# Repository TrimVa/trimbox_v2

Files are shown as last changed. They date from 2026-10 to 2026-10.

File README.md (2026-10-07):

# TrimBox

Enregistreur de télémétrie **GPS + inertiel** pour voitures radiocommandées,
avec **chronométrage au tour** affiché et annoncé sur la radio, **console web**
d'analyse et **mise à jour par Wi-Fi**. Construit autour d'un **ESP32-S3**.

> **État :** firmware **2.0-a16**, console **1.7.18**. Tout est écrit et testé
> sur PC, dans un navigateur et dans un émulateur ESP32-S3. **Essais sur le
> vrai matériel en cours** : GPS, IMU et script Lua sur la MT12 validés ; reste
> le roulage. Voir [les bancs d'essai](#bancs-dessai-à-la-réception-du-matériel).

---

## Sommaire

1. [Ce que fait le module](#ce-que-fait-le-module)
2. [Matériel](#matériel)
3. [Câblage](#câblage)
4. [Mise en route](#mise-en-route)
5. [Utilisation au bord de la piste](#utilisation-au-bord-de-la-piste)
6. [Console web](#console-web)
7. [Radio MT12 et script Lua](#radio-mt12-et-script-lua)
8. [Mises à jour du firmware](#mises-à-jour-du-firmware)
9. [Personnalisation](#personnalisation)
10. [Moniteur série et DEL](#moniteur-série-et-del)
11. [Sécurité et robustesse](#sécurité-et-robustesse)
12. [Dépannage](#dépannage)
13. [Contenu du dépôt](#contenu-du-dépôt)
14. [Compilation et tests automatiques](#compilation-et-tests-automatiques)
15. [Limites connues et suite du projet](#limites-connues-et-suite-du-projet)
16. [Documentation](#documentation)

---

## Ce que fait le module

| Fonction | Détail |
|---|---|
| **Enregistrement autonome** | GPS à 25 Hz + accéléromètre et gyroscope, sur la mémoire interne de 16 Mo. Aucun téléphone nécessaire pendant le roulage. |
| **Autonomie mémoire** | **01h42min à 25 Hz**, 02h08min à 20 Hz, 04h17min à 10 Hz, 08h34min à 5 Hz, 42h52min à 1 Hz (154 333 points). |
| **Enregistrement automatique** | l'enregistrement s'ouvre tout seul dès que la voiture roule et se ferme après 30 s à l'arrêt : **un roulage = une session**, sans rien toucher. Réglable, ou remplaçable par les boutons de la console. |
| **Filtres d'enregistrement** | attente du GPS, pause sans signal, extinction après inactivité. Rien n'est stocké au stand. |
| **Chrono embarqué** | calculé dans le module à 25 Hz, temps interpolés entre deux mesures (précision de l'ordre de la milliseconde). Mode **circuit** (une ligne, un temps par tour) ou **dragster** (départ + arrivée, chronos 0-30 / 0-50 / 0-80 km/h et 25 / 50 / 100 m). |
| **Pose de ligne depuis la radio** | voiture **arrêtée sur la ligne** : la commande arme la ligne, qui est posée dans le sens du départ dès que la voiture démarre (dans les 10 s) ; ce départ compte. Voiture **lancée** : la ligne est posée là où passe la voiture, perpendiculaire à sa trajectoire. Conservée d'une session à l'autre. |
| **Télémétrie radio** | position GPS, vitesse, état, et un message par tour (temps + écart au meilleur) vers la MT12, qui **annonce les temps à voix haute**. |
| **Console Bluetooth** | depuis la page GitHub du projet, sur Chrome Android. Comme le Wi-Fi, le Bluetooth se coupe quand la voiture roule et revient 30 s après l'arrêt. |
| **Console Wi-Fi** | le module ouvre son propre réseau quand la voiture est arrêtée depuis 30 s, et le coupe dès qu'elle roule. Fonctionne aussi sur **iPhone**, sans Internet. |
| **Analyse** | tracé coloré par vitesse, zoom, tours et parcours, forces G, temps en l'air, statistiques au survol du tracé, comparaison de sessions (portion choisie en glissant sur le profil, statistiques par session). Les **lignes posées depuis la radio** sont reprises d'office, et les **tours calculés en course** par le module s'affichent à côté de ceux de la console. |
| **Exports** | VBO (RaceChrono, Circuit Tools), CSV, GPX ; import de ces mêmes formats. |
| **Mise à jour Wi-Fi** | depuis le téléphone, avec retour automatique à la version précédente si la nouvelle ne démarre pas correctement. |

---

## Matériel

| Élément | Référence utilisée | Rôle |
|---|---|---|
| Carte | **ESP32-S3-DevKitC-1, module WROOM-1-N16R8** | 16 Mo de flash, 8 Mo de PSRAM, Bluetooth, Wi-Fi |
| GPS | **HGLRC M100 Mini** (u-blox M10) | position et vitesse à 25 Hz |
| Centrale inertielle | module **LSM6DS3 / LSM6DS3TR-C** (I2C) | accélérations ±16 g, rotations ±2000 °/s |
| Récepteur | **RadioMaster ER5C-i** (ExpressLRS 2,4 GHz) | commande de la voiture + liaison CRSF avec le module |
| Radio | **RadioMaster MT12** (EdgeTX) | affichage du chrono, pose des lignes |
| ESC | **XC-E8** | aucune liaison : son port X-Bus est une entrée (voir ci-dessous) |
| Alimentation | régulateur abaisseur **5 V, ≥ 1 A** | depuis le BEC de l'ESC (6 à 8,4 V) |

Au banc, l'USB de la carte suffit à tout alimenter.

⚠️ **Le module ne pilote jamais la voiture.** Direction et ESC restent sur
les sorties du récepteur : si le module plante, la voiture reste pilotable.

---

## Câblage

Schéma de câblage

Schéma vectoriel : [SVG](docs/cablage-trimbox-s3.svg) · [PDF à imprimer](docs/cablage-trimbox-s3.pdf) (régénéré par `tools/gen_cablage.py`).

| Module | Broche du module | ESP32-S3-DevKitC-1 |
|---|---|---|
| **GPS M100 Mini** | VCC | **5V** |
| | GND | GND |
| | TX | **GPIO 18** |
| | RX | **GPIO 17** |
| **IMU LSM6DS3** | VCC | **3V3** |
| | GND | GND |
| | SDA | **GPIO 8** |
| | SCL | **GPIO 9** |
| **Récepteur ER5C-i** | sortie 2 (Serial TX) | **GPIO 16** |
| | sortie 3 (Serial RX) | **GPIO 15** |
| | − | GND |
| **Alimentation (voiture)** | régulateur 5 V | **5V** + GND |

**Boîtier imprimé 3D (1/10)** : [docs/boitier/trimbox-boitier.3mf](docs/boitier/trimbox-boitier.3mf),
sans aucune vis : carte clipsée dans le fond, GPS (antenne à l'air libre par
une ouverture) et IMU clipsés dans le couvercle, trou pour voir la DEL, dessous
plat pour adhésif double face + passants pour colliers. Mesures, impression et montage : [docs/boitier/LISEZMOI.md](docs/boitier/LISEZMOI.md).

Réglages du récepteur (interface web de l'ER5C-i, onglet *Model*) :
sorties 2 et 3 en **Serial TX / RX, protocole CRSF** ; direction sur la
sortie 1 (CH1) ; ESC sur la sortie 4 (**CH2**).

Règles à respecter :

- **Jamais plus de 3,3 V sur une broche GPIO** : l'ESP32-S3 ne tolère pas le 5 V.
- **Jamais le BEC (6 à 8,4 V) directement sur la broche 5V** de la carte :
  toujours passer par le régulateur 5 V.
- Broches à ne pas utiliser : 35, 36, 37 (mémoire PSRAM), 19 et 20 (USB),
  0, 3, 45, 46 (démarrage).
- L'IMU se visse **rigidement** sur le châssis, près du centre de gravité,
  axes alignés sur la voiture (pas sur mousse).

---

## Mise en route

Détail pas à pas : **[DEMARRAGE.md](DEMARRAGE.md)**. En résumé :

1. **Envoyer ce dépôt sur GitHub.** L'onglet **Actions** compile et teste
   tout seul (10 à 15 min la première fois).
2. **Activer GitHub Pages** (*Settings → Pages → branche `main`, dossier
   `/ (root)`*) pour la console Bluetooth en ligne.
3. **Premier flash, une seule fois, par câble depuis un ordinateur** :
   page **Releases** du dépôt → dernière version → `trimbox_s3-complet.bin`, avec
   https://espressif.github.io/esptool-js/ (Chrome ou Edge), adresse **0x0**,
   prise **USB** de la carte.
4. **Vérifier** : 30 s après la mise sous tension, le Wi-Fi
   `TrimBox-Buggy-1` apparaît (mot de passe `trimbox-rc`, à changer dans
   *Réglages → Véhicule et point d'accès*) ; http://192.168.4.1/
   affiche la console et la version du firmware en haut à droite.
5. **Radio** : copier `lua/trmbox.lua` sur la MT12 et régler le mixage de CH8
   ([lua/LISEZMOI.md](lua/LISEZMOI.md)).

---

## Utilisation au bord de la piste

1. **Brancher la batterie de la voiture.** Le module démarre toujours
   **enregistrement arrêté**.
2. **Rien à faire** : l'enregistrement démarre tout seul dès que la voiture
   roule (au-dessus du seuil d'arrêt, 5 km/h par défaut) et se ferme après
   30 s à l'arrêt. Chaque roulage donne une session. Les boutons *Démarrer*
   et *Arrêter* de la console restent disponibles, et la case **Démarrer et
   arrêter tout seul** permet de revenir à la commande manuelle.
3. **Rouler.** Le Wi-Fi **et le Bluetooth** du module se coupent dès que la
   voiture dépasse 7 km/h, pour ne pas gêner la radio ; ils reviennent seuls
   30 s après l'arrêt.
4. **Poser la ligne** (une fois par piste) : voiture **arrêtée sur la ligne**,
   sur la MT12 page *Lignes*, molette sur « Poser DEPART », **ENT**, puis
   **démarrer dans les 10 s** : la ligne est posée dans le sens du départ, et
   ce départ compte déjà. En roulant (> 7 km/h), la même commande pose la
   ligne tout de suite, là où passe la voiture.
5. **Chaque tour** : la radio annonce le temps ; double bip aigu avant
   l'annonce s'il s'agit du meilleur tour.
6. **Au stand** : 30 s après l'arrêt de la voiture, le Wi-Fi revient. Le
   téléphone s'y reconnecte, la console aussi : **télécharger** la session,
   analyser, exporter.

Mode **dragster** : poser aussi la ligne d'**arrivée** (« Poser ARRIVEE »).
Un temps par passage départ → arrivée, plus les chronos intermédiaires.

---

## Console web

Un seul fichier (`index.html`), sans aucune dépendance : elle fonctionne sans
réseau. Trois sources de données, au choix en haut de page :

| Source | Quand | Adresse |
|---|---|---|
| **Bluetooth** | Chrome sur Android, ordinateur | `https://<pseudo>.github.io/<dépôt>/` |
| **Wi-Fi** | tout téléphone, dont iPhone ; au stand | `http://192.168.4.1/` (Wi-Fi du module) |
| **Démo** | sans matériel, pour découvrir | `…/index.html?demo=1` |

Fonctions : données en direct, état de la mémoire, démarrage / arrêt et
réglages de l'enregistrement, téléchargement et effacement, analyse
(tracé, tours, dragster, G, sauts), comparaison, exports VBO / CSV / GPX,
mise à jour du firmware (en Wi-Fi), thème clair / sombre et **couleur
d'accent** au choix (bouton palette), installable comme une application
(PWA). L'en-tête affiche la version de la console et celle du firmware de la
carte connectée.

La mise en page s'adapte à l'écran : une colonne sur téléphone (dès 320 px),
une colonne plus large sur tablette. Sur ordinateur, la console occupe **toute
la largeur** avec des **onglets** *Appareil*, *Analyse*, *Sessions* et
*Réglages* ; dans chaque onglet, les panneaux se partagent la ligne.

**Fond satellite en Wi-Fi.** Le point d'accès de la TrimBox n'a pas
Internet : les images satellite passent par la **4G du téléphone**. Pour cela :

- sur Android, activez les **données mobiles quand le Wi-Fi n'a pas
  Internet** (option « Basculer vers les données mobiles » ou « Wi-Fi
  adaptatif », selon la marque) ;
- ouvrez la console dans **Chrome** (`http://192.168.4.1`), et non dans la
  fenêtre « Se connecter à TrimBox-… » qui s'ouvre toute seule : cette
  fenêtre est limitée au Wi-Fi, les images ne peuvent pas y arriver.

Sans réponse d'Internet, la console garde le fond satellite actif, affiche une
explication et réessaie toutes les 10 s : la carte apparaît dès que la 4G
répond. Le reste fonctionne à l'identique, et le téléchargement est bien plus
rapide qu'en Bluetooth. Sans réseau mobile, deux solutions :

- **après la séance** : télécharger la session (CSV / GPX / VBO), puis la
  rouvrir dans la console en ligne, avec *Ouvrir des enregistrements* ;
- **au bord de la piste** : utiliser la console en ligne connectée **par
  Bluetooth**.

**Voiture à l'arrêt.** Une voiture posée semble « dériver » de 1 à 3 m à cause
du bruit du GPS. Pour l'éviter, le firmware fige la position et met la
vitesse à 0 dès que la voiture est immobile :
- **quand** : vitesse sous 1,1 km/h pendant 0,2 s, sans mouvement vu par l'IMU ;
- **reprise** : dès que la vitesse dépasse 2,2 km/h, que l'IMU bouge, ou que la
  voiture s'est éloignée de 4 m ;
- **pour enregistrer le GPS brut** : `STILL_HOLD 0` dans `config.h`.

---

## Radio MT12 et script Lua

Script `lua/trmbox.lua` → carte SD de la radio, `SCRIPTS/TELEMETRY/`.
Mode d'emploi complet : **[lua/LISEZMOI.md](lua/LISEZMOI.md)**.

- **Page Chrono** : dernier tour en grand, numéro, écart, meilleur tour,
  tours précédents ; état du module, lignes posées, indicateur Wi-Fi.
- **Page Machine** : vitesse (0 sous 3 km/h), vitesse maximale, satellites,
  qualité de liaison, RSSI, altitude, **tension de la batterie** (capteur du
  récepteur) et **date et heure du GPS** en heure locale.
- **Page Lignes** : poser le départ, l'arrivée, effacer.
- **Mixage CH8, indispensable** : *Modèle → Mixeur → CH8*, source **MAX**,
  poids **GV9**, mode « ajouter ». Sans lui, aucune commande de pose ne part
  de la radio. La page *Lignes* affiche la valeur réelle de la voie (`CH8
  +0%`), qui doit passer à ±100 % pendant un envoi. Un inter 3 positions sur
  CH8 marche aussi sans le script (haut 0,5 s = départ, bas 0,5 à 3 s =
  arrivée, bas 3 s = effacement).
- **Réglage ExpressLRS** : *Telem Ratio* **1:16** ou plus fréquent, sinon
  des messages de tour peuvent manquer.
- **Annonces vocales** : « meilleur tour », le temps du tour, l'écart avec le
  tour précédent (« moins 0,35 », « plus 1,00 », « égal »), et les accusés
  de pose de ligne (« départ posé », « vitesse trop faible »…). Les nombres
  viennent du pack vocal de la radio ; les 12 mots du script sont fournis dans
  `lua/SOUNDS/trimbox/` (copier `lua/SOUNDS` à la racine de la carte SD). Ils
  ont été produits par `tools/sons/generer-voix.bat` avec la voix Azure du pack
  EdgeTX (liste : `tools/sons/liste-sons-mt12.csv`). Sans eux, des bips les
  remplacent. `tools/sons/generer-mot.bat` produit à la demande d'autres mots
  ou phrases avec la même voix (texte et nom demandés, écoute avant d'enregistrer).
- **Date et heure GPS** : le module envoie la trame CRSF `0x03` une fois par
  seconde. Il faut **ExpressLRS 4.1 ou plus récent** sur l'émetteur **et** sur
  le récepteur pour qu'elle soit relayée, et une version d'EdgeTX qui la
  décode : après *Découvrir les capteurs*, un capteur **`Date`** apparaît.
  Avec l'option *Ajuster l'horloge* de ce capteur, la radio se met à l'heure
  toute seule. Le script affiche l'heure locale (France par défaut, heure
  d'été automatique ; réglages `TZ_OFFSET` et `TZ_EU_DST`).

Messages envoyés à la radio (capteur `FM`) :

| Message | Sens |
|---|---|
| `L12 21.345+0.35` | tour 12 en 21,345 s, 0,35 s de plus que le meilleur |
| `S REC C` | état (REC / PAUSE / STOP / NOFIX) et lignes (C circuit, D dragster, - aucune) |
| `R 0-50 2.184` | chrono intermédiaire (dragster) |
| `K DEPART OK` | accusé de pose de ligne (ou `VIT FAIBLE`, `PAS DE FIX`, `EFFACE`) |
| `W WIFI ON` | Wi-Fi de la console allumé / coupé |
| `U MAJ OK` | étapes d'une mise à jour du firmware |

---

## Mises à jour du firmware

**Par Wi-Fi, sans ordinateur :**

1. Modifier le code dans GitHub (bouton crayon) et valider : la compilation
   repart seule.
2. Page **Releases** du dépôt → dernière version → `trimbox_s3-app.bin`
   (publiée automatiquement quand tout est vert et que `FIRMWARE_VER` a
   changé ; sinon *Actions* → compilation verte → artefact
   **firmware-s3-app**).
3. Voiture **et** enregistrement arrêtés : console Wi-Fi → **Mise à jour du
   firmware** → choisir le fichier → **Envoyer au module** (environ 10 s).
4. La console se reconnecte et affiche « ✓ Nouvelle version active ».

Filets de sécurité :

- mauvais fichier refusé avec un message clair (fichier « complet », .uf2
  de la v1, autre projet, image corrompue) ;
- l'ancienne version n'est jamais effacée pendant l'envoi ;
- la nouvelle version ne se **valide qu'après 15 s** de bon fonctionnement ;
  si elle plante ou se fige avant, le module **revient seul** à la
  précédente ;
- page de secours : http://192.168.4.1/update.

⚠️ `trimbox_s3/partitions.csv` ne doit **jamais** changer dans une mise à jour
Wi-Fi : la table de partitions ne se remplace que par câble.

---

## Personnalisation

Dans **`trimbox_s3/src/config.h`** :

| Réglage | Par défaut | Rôle |
|---|---|---|
| `DEVICE_NICKNAME` | `"Buggy 1"` | nom du véhicule **par défaut** (16 caractères max) : `TrimBox Buggy 1` en Bluetooth, `TrimBox-Buggy-1` en Wi-Fi ; se change ensuite dans la console |
| `WIFI_PASS` | `"trimbox-rc"` | mot de passe Wi-Fi **par défaut** (8 à 63 caractères) ; se change dans la console |
| `WIFI_AUTO_DEFAULT` | `1` | Wi-Fi automatique à l'arrêt (0 : seulement à la demande) |
| `WIFI_AUTO_ON_S` | `30` | secondes d'arrêt avant l'ouverture du Wi-Fi |
| `CRSF_LINE_CHANNEL_DEFAULT` | `8` | voie radio de pose de ligne |
| `PIN_LED_RGB` | `48` | DEL de la carte : **38** sur une DevKitC-1 v1.1 |
| `AXIS_*` | capteur à plat, x vers l'avant | orientation de l'IMU selon son montage |

Les autres valeurs du fichier ont été fixées par mesure ou par contrainte
matérielle : ne pas les modifier sans raison (voir les cahiers des charges).

Plusieurs voitures : un nom de véhicule différent par module suffit à les
distinguer (Bluetooth, Wi-Fi et console). Il se change dans la console,
*Réglages → Véhicule et point d'accès*, sans recompiler.

---

## Moniteur série et DEL

Moniteur série à **115 200 bauds**, sur la prise **USB** de la carte
(onglet *Console* d'esptool-js, moniteur de l'IDE Arduino, PuTTY…) :

| Touche | Effet |
|---|---|
| `s` | arrêt d'urgence de l'enregistrement |
| `r` | démarrer l'enregistrement (essai sans téléphone) |
| `w` | Wi-Fi marche / arrêt |
| `i` | état : mémoire, enregistrement, configuration, lignes |
| `b` | banc d'essai : cadence GPS, IMU, radio, Bluetooth, Wi-Fi, partition du firmware |
| `m` | mesures de la centrale inertielle en direct (10 lignes, mg et c°/s) |
| `z` | configuration par défaut (données conservées) |
| `x` | nom du véhicule et mot de passe Wi-Fi d'origine (mot de passe oublié) |
| `?` | aide |

**Bouton BOOT**, appui long de 3 s : Wi-Fi marche / arrêt.

**DEL de la carte :**

| Couleur | Sens |
|---|---|
| rouge clignotant | GPS ou mémoire absents (normal au banc sans GPS) |
| rouge fixe | enregistrement en cours |
| orange | enregistrement en pause |
| vert clignotant | GPS calé, prêt |
| bleu fixe | console connectée |
| bleu clignotant | Wi-Fi ouvert, en attente du téléphone |

Les couleurs se superposent : rouge + bleu = violet (enregistrement en cours, console connectée).

---

## Sécurité et robustesse

- **Coupure d'alimentation** (batterie arrachée en pleine session) : les
  données déjà enregistrées restent intactes et téléchargeables ; la
  configuration est écrite en double exemplaire ; l'enregistrement **ne
  reprend jamais tout seul** au redémarrage ; les points incomplets sont
  écartés à la lecture.
- **Effacement de la mémoire** : impossible pendant un enregistrement, et
  non annulable une fois lancé (il ne dure que quelques secondes).
- **Wi-Fi et Bluetooth coupés en roulant**, quel que soit le réglage : la
  liaison de commande 2,4 GHz passe avant la console. Rallumage automatique
  après 30 s d'arrêt (`BLE_AUTO_OFF 0` dans `config.h` pour garder le
  Bluetooth en permanence).
- **Chien de garde** : si le programme se fige plus de 5 s, la carte
  redémarre seule.
- **Protocole** : trames avec somme de contrôle, réassemblage tolérant aux
  pertes ; une trame corrompue ne peut pas produire de valeurs absurdes
  dans l'analyse.

---

## Dépannage

| Problème | Piste |
|---|---|
| Carte non détectée pour le flash | câble de **données**, prise **USB** ; BOOT maintenu + RST, relâcher BOOT |
| Pas de Wi-Fi `TrimBox-…` | attendre 30 s voiture arrêtée ; appui long BOOT ; touche `w` ; vérifier le journal série |
| « Pas d'accès Internet » sur le téléphone | normal : rester connecté et ouvrir http://192.168.4.1/ |
| `[gnss] AUCUNE RÉPONSE` | TX et RX croisés (GPS TX → GPIO 18), alimentation 5 V |
| GPS à moins de 25 Hz | normal à l'intérieur ; si Galileo est coupé tout seul, le noter (réglage automatique) |
| `[imu] ABSENTE` | SDA = 8, SCL = 9, 3,3 V, masse |
| Radio : « PAS DE LIAISON » | récepteur : sorties 2/3 en CRSF, TX/RX croisés ; *Découvrir les capteurs* sur la MT12 |
| Des tours manquent sur la radio | *Telem Ratio* ExpressLRS trop bas : 1:16 ou plus fréquent |
| Rien ne se passe à la pose de ligne (la page *Lignes* affiche `CH8 +0%`) | mixage CH8 absent : *Modèle → Mixeur → CH8*, source MAX, poids GV9, mode Ajouter |
| « délai dépassé » après une pose à l'arrêt | démarrer dans les 10 s qui suivent la commande |
| Mise à jour refusée | lire le message : enregistrement en cours, mauvais fichier, voiture en mouvement |
| Console : ancienne version affichée | recharger la page ; en Bluetooth, vider le cache du navigateur |
| La compilation GitHub échoue | ouvrir l'étape en rouge dans *Actions* ; le premier test en échec indique la cause |

---

## Contenu du dépôt

```
trimbox_s3/                      firmware ESP32-S3 (croquis Arduino)
│   trimbox_s3.ino               point d'entrée
│   partitions.csv               table de partitions 16 Mo — NE PAS MODIFIER
│   LISEZMOI.md                  câblage, premier flash, bancs d'essai
└── src/
    ├── config.h                 réglages et brochage
    ├── app.cpp                  boucle principale, commandes, chrono, Wi-Fi auto
    ├── console_gz.h             console intégrée (générée, ne pas éditer)
    ├── core/                    logique SANS matériel, testée sur PC :
    │                            protocoles (TrimBox, UBX, CRSF), chrono,
    │                            automate d'enregistrement, pose de ligne,
    │                            configuration A/B, serveur HTTP/WebSocket,
    │                            contrôle des mises à jour
    └── hw/                      pilotes : GPS, IMU, mémoire, Bluetooth,
                                 Wi-Fi, radio, mise à jour
lua/trmbox.lua                   script de télémétrie MT12 (+ LISEZMOI.md)
lua/SOUNDS/trimbox/              les 12 mots des annonces vocales (à copier sur la carte SD)
index.html                       console web (GitHub Pages et firmware)
trimbox-sw.js                    service worker (console hors ligne)
trimbox-diy-console-demo.html    redirection des anciens liens vers la démo
tools/embed_console.py           intègre index.html au firmware
tools/gen_cablage.py             génère le schéma de câblage (docs/)
tools/gen_boitier.py             génère le boîtier imprimé 3D (docs/boitier/)
tools/imu_test/                  croquis de test de la centrale inertielle seule
docs/                            schéma de câblage (SVG, PDF) et boîtier 3D
tools/sons/                      sons de la radio : liste (CSV) + génération Azure des mots du script
tools/xbus_probe/                sonde ESP32 du port X-Bus (piste close)
tests/native/                    tests de la logique (g++) + comparaison avec la console
tests/web/                       console dans un navigateur, avec le serveur du firmware
tests/lua/                       script Lua avec l'API EdgeTX simulée
tests/qemu/                      firmware complet dans l'émulateur ESP32-S3
.github/workflows/build-s3.yml   compilation et tests à chaque envoi
CAHIER-DES-CHARGES.md            spécification complète (matériel, protocole, firmware, radio, console, pièges)
trimbox-etat-projet.json         état du projet, pour reprendre avec une IA
REPRISE-IA.md                    marche à suivre pour reprendre le développement avec une IA
```

---

## Compilation et tests automatiques

À chaque envoi sur GitHub, l'onglet **Actions** enchaîne :

| Étape | Vérifie |
|---|---|
| Tests natifs | protocoles, chrono (bancs v1 : 5 tours de 20,00 s, ligne en 4 endroits ; dragster à 6 m/s²), automate d'enregistrement, pose de ligne, configuration A/B, serveur web, contrôles de mise à jour — plus de 950 vérifications |
| Chrono firmware = console | les mêmes trajets rejoués dans les deux : écart maximal 1 ms |
| Script Lua | messages, sons, impulsions GV9, affichage (API EdgeTX simulée) |
| Compilation | ESP32-S3, core `esp32:esp32@3.3.12`, NimBLE-Arduino 2.5.1 (versions figées) |
| Console dans un navigateur | chargement, connexion Wi-Fi, direct, téléchargement, reconnexion, couleur, envoi du firmware compilé |
| Émulateur | Wi-Fi automatique à l'arrêt, pose de ligne par le script Lua, tours de 12,000 s reçus sans perte, coupure d'alimentation, retour arrière après une mise à jour qui plante |

Artefacts produits :

| Artefact | Contenu | Usage |
|---|---|---|
| `firmware-s3-complet` | `trimbox_s3-complet.bin` (+ fichiers séparés) | premier flash, par câble, adresse 0x0 |
| `firmware-s3-app` | `trimbox_s3-app.bin` | mise à jour par Wi-Fi |
| `capture-console-wifi` | capture d'écran | contrôle visuel de la console |

Il faut être **connecté à GitHub** pour télécharger un artefact.

**Release automatique** : sur la branche `main`, quand tous les jobs sont
verts et que `FIRMWARE_VER` (`trimbox_s3/src/config.h`) n'a pas encore été
publiée, le job *Publication* crée la release `firmware-<version>` : les deux
`.bin`, bootloader et partitions séparés, la console `index.html`, le pack
radio `trimbox-radio.zip`, `SHA256SUMS.txt`, et des notes complètes (usage de
chaque fichier, procédures, nouveautés depuis la release précédente,
empreintes). Téléchargeable **sans compte GitHub**. Une version déjà publiée
n'est jamais écrasée : incrémenter `FIRMWARE_VER` pour publier.

---

## Limites connues et suite du projet

- **Essais matériels en cours** : GPS validé sur la carte (fix 3D,
  13 satellites, ~20 Hz), IMU validée avec `tools/imu_test` (|a| = 0,99 g au
  repos), script Lua validé sur la MT12 (affichage, tours, annonces vocales,
  accusés de pose). Restent à valider : mixage CH8 et pose de ligne depuis la
  radio, enregistrement automatique et chrono en roulage, Bluetooth et Wi-Fi
  en conditions réelles, boîtier imprimé.
- **ESC XC-E8, abandonné** : son port X-Bus (paramètre *PLine* de
  l'application) est une **entrée**. Analyseur logique et sonde ESP32 l'ont
  confirmé : ligne tenue en haut par une résistance de tirage, aucune
  émission, aucune réponse à une poignée de main. Les autres choix de *PLine*
  (Max.Brake, Max.Rev, Acc, DragBrake) sont eux aussi des entrées, et
  *ProtocolId* n'est qu'un numéro d'appareil sur le bus. Il n'y a donc pas de
  télémétrie à lire sur cette prise. La tension de batterie remonte déjà par
  la radio. Détail des essais : cahier des charges §13.
- **Batterie** : la tension s'affiche sur la radio (capteur du récepteur), pas
  dans la console (octet batterie toujours à 0).
- **Premier flash** : nécessite un ordinateur, une seule fois.

### Bancs d'essai à la réception du matériel

Dans l'ordre, en notant la sortie de la touche `b` à chaque étape
(détail dans [trimbox_s3/LISEZMOI.md](trimbox_s3/LISEZMOI.md)) :

1. carte seule : démarrage, mémoire, Wi-Fi, console ;
2. + GPS, dehors : 25 Hz — ✅ fix 3D, 13 satellites, ~20 Hz ;
3. + IMU : capteur reconnu — ✅ avec `tools/imu_test` ;
4. + récepteur : liaison CRSF, capteurs découverts sur la MT12 — ✅ messages
   du chrono reçus par le script Lua ;
5. console : connexion, enregistrement, téléchargement, effacement ;
6. roulage : pose de ligne, tours sur la radio, comparaison avec la console.

---

## Documentation

| Document | Contenu |
|---|---|
| [DEMARRAGE.md](DEMARRAGE.md) | mise en ligne, premier flash, mises à jour |
| [trimbox_s3/LISEZMOI.md](trimbox_s3/LISEZMOI.md) | câblage, flash, moniteur série, bancs d'essai |
| [lua/LISEZMOI.md](lua/LISEZMOI.md) | installation du script, mixage, utilisation |
| [CAHIER-DES-CHARGES.md](CAHIER-DES-CHARGES.md) | spécification complète du projet : matériel, protocole, firmware, radio, Wi-Fi et Bluetooth, mise à jour, console, script Lua, tests, **règles dures (§0)** et **pièges connus (§12)** |
| [trimbox-etat-projet.json](trimbox-etat-projet.json) | état du projet, à fournir à une IA pour reprendre le travail |
| [REPRISE-IA.md](REPRISE-IA.md) | marche à suivre et texte à coller pour reprendre avec une IA |

Le format de trame dérive de la documentation du protocole BLE RaceBox
(révision 8). Aucune compatibilité avec l'application RaceBox officielle n'est
recherchée.

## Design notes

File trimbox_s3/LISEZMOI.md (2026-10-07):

# TrimBox — firmware 2.0-a16

Firmware ESP32-S3. Spécification : `CAHIER-DES-CHARGES.md` (à la racine du
dépôt). État au 4 octobre 2026.

## Ce qui est fait, ce qui ne l'est pas

| Fonction | État |
|---|---|
| GNSS M10 : détection de vitesse, configuration, NAV-PVT 25 Hz | ✅ testé sous émulateur ; ✅ **sur la carte** (fix 3D, 13 satellites, ~20 Hz) |
| Enregistrement en flash (01h42min à 25 Hz), filtres arrêt / sans fix / extinction | ✅ testé (natif + émulateur) |
| Voiture posée : vitesse 0 et position figée, jugées par l'agitation de l'IMU (GPS seul si IMU absente) ; plus de faux départ avec peu de satellites (2.0-a16) | ✅ testé sur PC (scénario de l'essai du 07/10) ; ⚠️ à vérifier sur la voiture (touche `m` : « calme ») |
| Coupure d'alimentation : config A/B, pas de reprise, journal intact | ✅ testé sous émulateur |
| Bluetooth, protocole console v1 (état, config, téléchargement, effacement, FF F0) | ⚠️ compilé, **non testé** (pas de Bluetooth dans l'émulateur) |
| IMU LSM6DS3 / LSM6DS3TR-C, ±16 g, moyenne par période GNSS | ✅ capteur validé sur matériel avec `tools/imu_test` (\|a\| = 0,99 g) ; ⚠️ à revérifier dans le firmware complet (touche `m`) |
| CRSF : télémétrie GPS + messages texte vers la MT12 | ✅ testé sous émulateur ; ✅ messages reçus sur la MT12 |
| Pose de ligne par la voie 8 (inter ou script Lua), en roulant ou à l'arrêt (ligne armée 10 s) | ✅ testé sous émulateur ; ⚠️ à essayer sur la voiture |
| Enregistrement automatique (un roulage = une session) | ✅ testé (natif) ; ⚠️ à essayer en roulage |
| Chronométrage embarqué (tours, dragster, chronos intermédiaires) | ✅ identique à la console à 1 ms (banc n°7) |
| Point d'accès Wi-Fi automatique (arrêt 30 s → allumé, roule → coupé) | ✅ logique testée sur PC (`core/airgate`) et sous émulateur (stand → roulage → arrêt) ; radio Wi-Fi non testée |
| Bluetooth coupé au roulage, rallumé après 30 s d'arrêt (`BLE_AUTO_OFF`) | ✅ logique testée sur PC (même `core/airgate`) ; ⚠️ à vérifier sur la carte (touche `b` : « BLE actif » / « COUPÉ ») |
| Console embarquée (v1.7.3, thèmes et couleur d'accent compris) + WebSocket | ✅ testée dans Chromium avec le vrai serveur du firmware |
| Mise à jour du firmware par Wi-Fi (OTA) + retour arrière automatique | ✅ envoi testé dans Chromium ; retour arrière testé sous émulateur avec le vrai chargeur de démarrage ; radio Wi-Fi non testée |
| ESC XC-E8 (X-Bus) | ❌ **abandonné** : le port X-Bus est une entrée, aucune télémétrie (§13) |
| Script Lua MT12 (`lua/trmbox.lua`) | ✅ testé avec l'API EdgeTX simulée, en chaîne complète sous émulateur, et **validé sur la MT12** |

## Câblage de banc (alimentation par l'USB de la carte)

| Module | Broche module | ESP32-S3-DevKitC-1 |
|---|---|---|
| GPS M100 Mini | VCC | **5V** |
| | GND | GND |
| | TX | **GPIO 18** |
| | RX | **GPIO 17** |
| IMU LSM6DS3 | VCC | **3V3** |
| | GND | GND |
| | SDA | **GPIO 8** |
| | SCL | **GPIO 9** |
| Récepteur ER5C-i | sortie 2 (Serial TX) | **GPIO 16** |
| | sortie 3 (Serial RX) | **GPIO 15** |
| | − | GND |

Le fil + du récepteur reste sur le BEC de l'ESC (ou sur le 5V de la carte au
banc). **Rien au-dessus de 3,3 V sur une broche GPIO.**

`GPIO 10` (GPS_EN) ne sert que si un transistor coupe l'alimentation du GPS.
Sans lui, le GPS reste alimenté en veille : c'est sans conséquence.

Branchez l'USB sur le port marqué **USB** (et non **UART**) : le journal du
firmware passe par là.

## Premier flashage

Il se fait **une fois, depuis un ordinateur** :

1. Télécharger `trimbox_s3-complet.bin` depuis la page **Releases** du dépôt
   (ou l'artefact `firmware-s3-complet` de la compilation GitHub).
2. Ouvrir <https://espressif.github.io/esptool-js/> dans Chrome ou Edge sur
   ordinateur, brancher la carte (port **USB**), *Connect*.
3. Adresse **0x0**, fichier `trimbox_s3-complet.bin`, *Program*.

Si la carte n'est pas détectée : maintenir **BOOT**, appuyer sur **RESET**,
relâcher **BOOT**, puis *Connect*.

⚠️ Le fichier complet **efface la mémoire d'enregistrement**. Ensuite, toutes
les mises à jour se font **par Wi-Fi, depuis le téléphone** (ci-dessous).

## Mettre à jour le firmware par Wi-Fi (sans PC)

1. Sur le téléphone : page **Releases** du dépôt GitHub → dernière version
   → `trimbox_s3-app.bin` (ou onglet **Actions** → compilation réussie →
   artefact **firmware-s3-app**).
2. Voiture **arrêtée**, enregistrement **arrêté**. Attendre le Wi-Fi du
   module (30 s) et ouvrir la console (http://192.168.4.1/).
3. Section **Mise à jour du firmware** → choisir le fichier → **Envoyer au
   module**. Environ 10 s. La radio affiche `U REDEMARRAGE`.
4. Le module redémarre, la console se reconnecte seule et affiche
   « ✓ Nouvelle version active : …, compilée le … ». Comparez avec l'heure de
   la compilation GitHub.
5. La nouvelle version se **valide seule après 15 s** de fonctionnement
   (`U MAJ OK` sur la radio).

**Filets de sécurité :**
- Le module refuse, avec un message clair : un fichier qui n'est pas un
  firmware TrimBox S3 (le « complet », un .uf2 de la v1, un autre projet…),
  une image corrompue, un envoi pendant un enregistrement ou en roulant.
- Tant que rien n'est accepté, **rien n'est modifié** : la mise à jour
  s'écrit dans la seconde moitié de la mémoire programme, l'ancienne version
  reste intacte.
- Si la nouvelle version plante, se fige plus de 5 s ou ne lit plus la
  mémoire avant sa validation, **le module revient tout seul à la version
  précédente** au redémarrage suivant. La console le signale : « ✗ Le module
  tourne toujours sur la version compilée le … ».
- Page de secours sans la console : **http://192.168.4.1/update**.
- Ne **jamais** modifier `partitions.csv` dans une mise à jour Wi-Fi : la
  table de partitions ne se change que par câble.

## Console par Wi-Fi (sans Bluetooth, fonctionne aussi sur iPhone)

1. Voiture **arrêtée depuis 30 s** (ou juste allumée) : le module ouvre le
   réseau **`TrimBox-Buggy-1`**, mot de passe **`trimbox-rc`** (à changer dans
   la console : *Réglages → Véhicule et point d'accès*). La MT12 affiche `W WIFI ON`.
2. Connectez le téléphone à ce réseau. Il propose en général d'ouvrir la page
   tout seul (portail captif) ; sinon, ouvrez **http://192.168.4.1/**.
3. La console se connecte seule, source **Wi-Fi**. Téléchargement nettement
   plus rapide qu'en Bluetooth.
4. Dès que la voiture roule (plus de 7 km/h), le point d'accès se **coupe**
   (`W WIFI OFF`) pour ne pas gêner la radio 2,4 GHz. Quand elle s'arrête à
   nouveau 30 s, il revient, et la console se **reconnecte d'elle-même**.

Forcer : **appui long (3 s) sur BOOT** ou touche `w` du moniteur série
(marche / arrêt). Le téléphone dira « pas d'accès Internet » : c'est normal,
restez connecté. Pour le fond satellite, ouvrez la console dans Chrome
(`http://192.168.4.1`) avec les données mobiles autorisées quand le Wi-Fi n'a
pas Internet : les images passent alors par la 4G.

Si la console affiche une ancienne version : la page n'est pas mise en cache
(`Cache-Control: no-cache`), rechargez simplement.

## Réglages radio

**Récepteur ER5C-i** (interface web du récepteur, onglet *Model*) :
sorties 2 et 3 en **Serial TX / Serial RX**, protocole **CRSF** ;
direction sur la sortie 1 (CH1), ESC sur la sortie 4 (**CH2**).

**MT12** : installer le script `lua/trmbox.lua` et le mixage de CH8
(voir `lua/LISEZMOI.md`). Sans le script, un inter sur **CH8** suffit
(3 positions de préférence) :
Haut 0,5 s = ligne de départ. Bas 0,5 à 3 s = ligne d'arrivée.
Bas 3 s = effacement. Voiture lancée (plus de 7 km/h) : la ligne est posée
aussitôt. Voiture arrêtée sur la ligne : la ligne est armée, démarrer dans les
10 s.
Puis *Télémétrie → Découvrir les capteurs* : GPS, vitesse, satellites et
**FM** (messages du chrono) apparaissent.

## Moniteur série (115 200 bauds)

| Touche | Effet |
|---|---|
| `s` | arrêt d'urgence de l'enregistrement |
| `r` | démarrer l'enregistrement (essai sans téléphone) |
| `w` | point d'accès Wi-Fi : marche / arrêt |
| `i` | état : mémoire, enregistrement, configuration, lignes |
| `b` | **banc d'essai** : cadence GNSS, IMU, CRSF (LQ, RSSI), Bluetooth, Wi-Fi, partition |
| `m` | mesures de la centrale inertielle en direct (10 lignes, mg et c°/s) |
| `z` | configuration par défaut (données conservées) |
| `x` | nom du véhicule et mot de passe Wi-Fi d'origine (mot de passe oublié) |
| `?` | aide |

`b` indique aussi la partition en cours (`app0` / `app1`) et « EN VALIDATION » juste après une mise à jour.

## Bancs d'essai à faire en recevant le matériel

Dans l'ordre (§11.2). Envoyez-moi la sortie de `b` à chaque étape.

1. **Carte seule** : le journal affiche la version, `mémoire : 0 / 154333`.
   Le GPS et l'IMU sont signalés absents : normal.
2. **+ GPS**, dehors : `[gnss] module trouvé`, 4 × `ACK`, puis `b` affiche
   **25,0 Hz**. Si Galileo est coupé automatiquement, le noter.
   ✅ fait : fix 3D, 13 satellites, ~20 Hz.
3. **+ IMU** : capteur trouvé à l'adresse **0x6A ou 0x6B** (identifiant
   0x69, 0x6A, 0x6B ou 0x6C accepté), puis `m` : environ 1000 mg sur l'axe
   vertical au repos. ✅ capteur validé avec `tools/imu_test`.
4. **+ récepteur** : `b` affiche `CRSF 150 trames/s` (ou le débit choisi),
   `liaison OK`, puis la MT12 découvre les capteurs. ✅ messages reçus sur la
   MT12.
5. **Console** (téléphone, <https://…github.io/…/>) : connexion, état,
   démarrage, arrêt, téléchargement, effacement.
6. **Roulage** : poser la ligne depuis la radio (script Lua ou inter),
   vérifier les tours sur la radio et l'enregistrement automatique, puis
   comparer avec la console après téléchargement.

## Tests sans matériel

```bash
make -C tests/native                      # logique : 900+ vérifications
node tests/native/console_check.js index.html tests/native/lap_cases.json
python3 tools/embed_console.py             # après toute modification d'index.html
g++ -std=c++17 -o tests/web/fakedev tests/web/fakedev.cpp trimbox_s3/src/core/*.cpp -lm
python3 tests/web/console_web_test.py tests/web/fakedev   # console dans Chromium
python3 tests/qemu/sim.py flash.bin       # émulateur (voir le workflow)
python3 tests/qemu/ota_rollback.py merged.bin app.bin app_qui_plante.bin
```

La compilation GitHub (`.github/workflows/build-s3.yml`) enchaîne le tout.

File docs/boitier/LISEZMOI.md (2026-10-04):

# Boîtier imprimé 3D — voiture 1/10 (v2, sans vis)

Fichier : **`trimbox-boitier.3mf`**. Le fond et le couvercle sont sur le même
plateau et déjà orientés pour l'impression. Le fichier est généré par
`tools/gen_boitier.py`, qui regroupe toutes les cotes en tête de fichier.

| | |
|---|---|
| Encombrement | 67,7 × 33 × 27 mm |
| Intérieur | 63,7 × 29 × 20 mm |
| Fixation | dessous **plat** pour adhésif double face, plus **2 passants** pour colliers (jusqu'à 5 mm de large) |
| Fermeture | **aucune vis** : 4 languettes à cran du couvercle s'enclenchent dans 4 fenêtres du fond |
| Dans le fond | carte ESP32-S3 : **rainure** côté USB et **2 crochets** côté antenne |
| Dans le couvercle | **GPS** clipsé sous une **ouverture** (antenne en vue directe du ciel), **IMU** clipsée, **trou de DEL** |

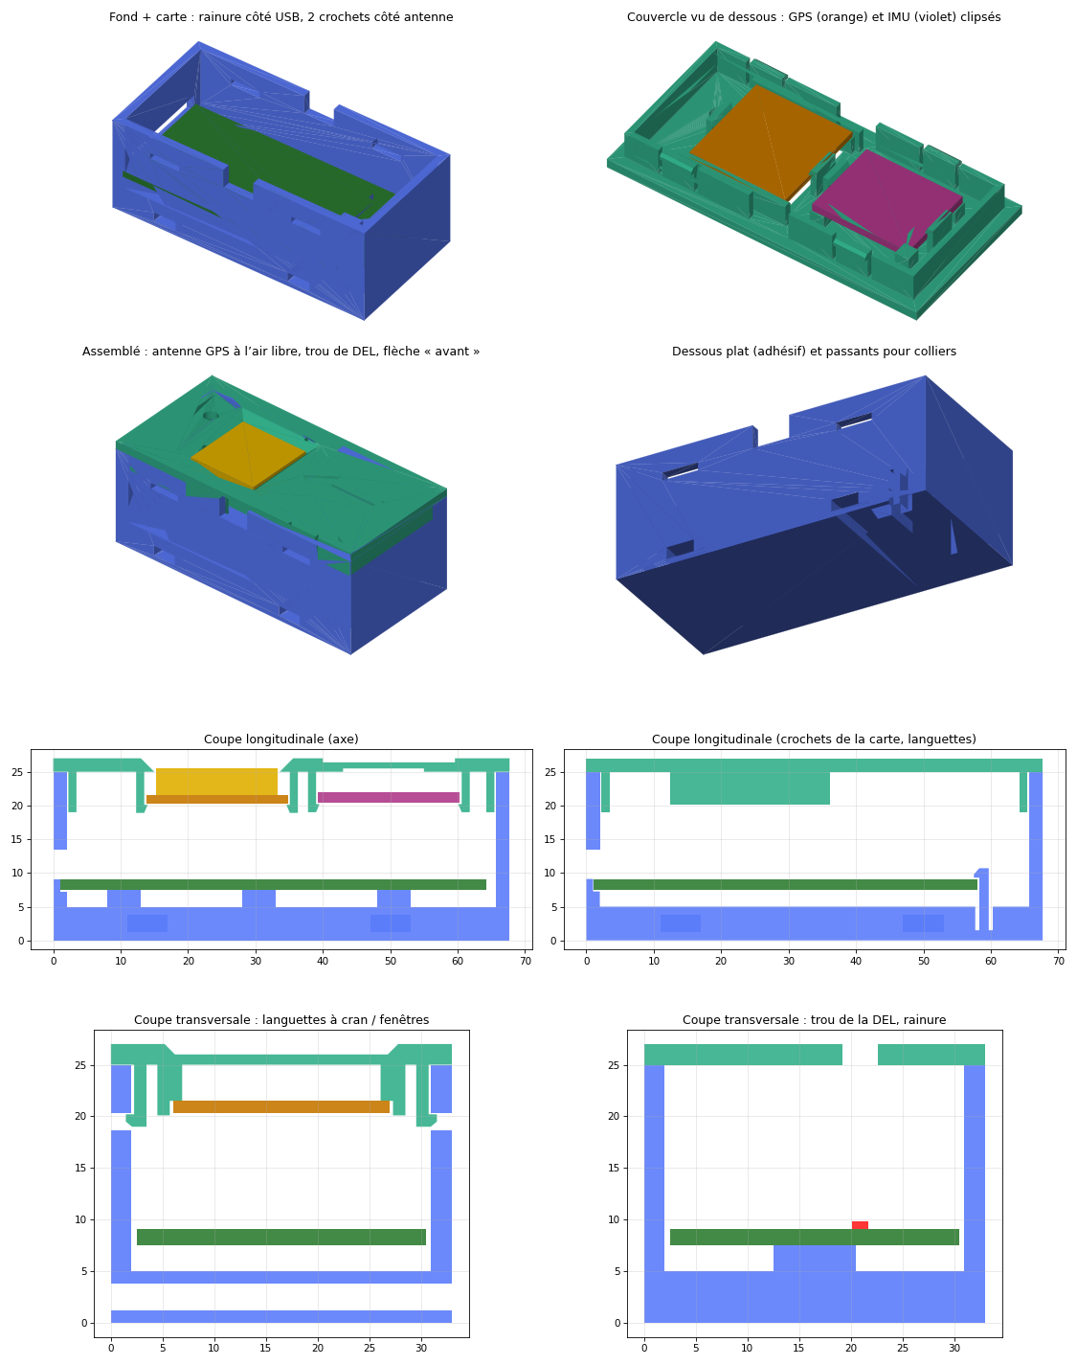
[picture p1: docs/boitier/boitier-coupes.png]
Coupes du boîtier


## Cotes utilisées

| Pièce | Cote | Réglage dans le script |
|---|---|---|
| Carte ESP32-S3-DevKitC-1 N16R8 | 57 × 28 × 1,6 mm (jeu de 0,5 mm) | `PCB_L`, `PCB_W`, `PCB_T`, `TOL` |
| Débord de l'antenne de la carte | 18 × 6,2 mm | `ANT_W`, `ANT_L` |
| DEL RGB de la carte | 8,8 mm du bord USB, 18,4 mm du bord « bas » | `LED_X`, `LED_Y` |
| Circuit du GPS HGLRC M100 | 21 × 21 × 1,2 mm | `GPS_PCB`, `GPS_PCB_T` |
| Antenne céramique du GPS | 18 × 18 mm, ouverture de 18,6 mm | `GPS_ANT` |
| Module IMU LSM6DS3 | **21 × 17 × 1,6 mm (à vérifier)** | `IMU_L`, `IMU_W`, `IMU_T` |

**Repère de la DEL.** Carte vue de dessus, composants vers le haut, prises
USB à gauche. Le bord « bas » est le grand côté le plus proche de vous. Si la
DEL mesurée se trouve de l'autre côté, remplacer `LED_Y` par `28 - 18.4`.

**Pour changer une cote**, modifier la valeur puis relancer
`python3 tools/gen_boitier.py` (dépendance : `pip install manifold3d`).

## Impression

- **PETG** de préférence. Les crochets et les languettes plient d'environ
  3 %, ce que le PETG supporte sans casser. Le PLA convient s'il n'est pas
  démonté souvent. Le PETG tient aussi mieux à la chaleur et au soleil.
- Couche 0,2 mm, 3 périmètres, remplissage 25 %, **sans supports**. Le
  couvercle s'imprime face lisse sur le plateau et l'ouverture du GPS est
  chanfreinée à 45°. L'ouverture USB, les fenêtres et les passants sont des
  ponts courts.
- Pas de filament chargé en carbone ou en métal : il gênerait le GPS et le
  Bluetooth / Wi-Fi.

## Montage (aucune vis)

1. **Carte ESP32-S3** (composants en haut) :
   - glisser le **bord USB** dans la **rainure** de la paroi, les prises face
     à l'ouverture ;
   - abaisser le bout antenne entre les deux crochets et appuyer jusqu'au
     **clic**. Les crochets tiennent la carte et encadrent l'antenne.
   - Pour la sortir, écarter les deux crochets vers le bout du boîtier.
2. **GPS**, antenne céramique **vers le couvercle** :
   - le poser entre les deux guides, sous l'ouverture carrée ;
   - appuyer jusqu'au clic des 2 crochets. L'antenne se retrouve dans
     l'ouverture et voit directement le ciel.
3. **IMU**, **composants vers le couvercle**, sur ses 4 plots :
   - aligner la flèche X du module sur la **flèche gravée** sous le
     couvercle (elle pointe vers le côté USB) ;
   - appuyer jusqu'au clic des 2 crochets.
   - Monté ainsi, le module a la même orientation que « posé à plat,
     composants en haut » : les réglages `AXIS_*` de `config.h` ne changent
     pas.
4. **Câbles** :
   - souder les fils sur la carte, en gardant de la longueur pour ouvrir le
     couvercle à côté du boîtier ;
   - faire sortir les fils vers le récepteur par l'une des **encoches** des
     grands côtés.
5. **Couvercle** : l'orienter de sorte que le **trou de DEL soit côté USB**,
   puis appuyer jusqu'au clic des 4 languettes. Pour l'ouvrir, enfoncer
   les languettes par les fenêtres avec un petit tournevis plat.
6. **Sur la voiture** :
   - **flèche du dessus vers l'avant** ;
   - adhésif double face sous le boîtier et un collier dans chaque passant ;
   - le plus haut et le plus dégagé possible pour le GPS, loin du moteur.

Il n'y a plus de logement de régulateur. La carte est alimentée en 5 V par la
prise servo du récepteur (BEC du variateur). Si un régulateur reste
nécessaire, il se place hors du boîtier, sur le faisceau.

Les prises USB restent accessibles boîtier fermé (flash, journal série), et la
DEL d'état se voit par son trou.

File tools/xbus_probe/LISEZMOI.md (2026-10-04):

# Sonde de la prise de données du variateur (« X-Bus »)

Croquis autonome pour l'ESP32-S3. Il remplace provisoirement le firmware
TrimBox, interroge la prise secondaire du variateur et affiche à l'écran tout
ce qui en revient. Le firmware TrimBox se reflashe ensuite normalement.

## 1. Mesurer avant de brancher

Variateur allumé, prise secondaire configurée sur **X-Bus**, mesure au
voltmètre entre le fil **signal** et le fil **−** :

| Tension au repos | Ce que ça veut dire | Câblage de la réception |
|---|---|---|
| ≈ 3,3 V | logique 3,3 V | fil signal directement sur **GPIO 4** |
| ≈ 5 V | logique 5 V | pont diviseur : 10 kΩ entre le fil et GPIO 4, 20 kΩ entre GPIO 4 et GND |
| ≈ 0 V | ligne tirée au bas, ou mauvais fil | vérifier le brochage avant d'aller plus loin |

**Les entrées de l'ESP32 ne supportent pas le 5 V.** En cas de doute, mets le
pont diviseur : il fonctionne dans les deux cas.

## 2. Câblage

| Prise du variateur | ESP32-S3 |
|---|---|
| − (noir ou marron) | **GND** — obligatoire |
| + (rouge) | **rien** : l'ESP32 est alimenté par l'USB |
| signal (orange) | **GPIO 5** à travers une résistance de **1 kΩ** (émission) et **GPIO 4** (réception, direct ou par le pont) |

La résistance de 1 kΩ protège les deux côtés si les deux parlent en même
temps : c'est une liaison à un seul fil, chacun son tour.

## 3. Essais

Flasher `xbus_probe.ino`, ouvrir le moniteur série à 115200, puis taper :

| Touche | Essai | Ce qu'on cherche |
|---|---|---|
| `a` | mesure des impulsions pendant 10 s + répartition des durées | des durées **multiples d'un même temps de bit** : signe d'une vraie liaison série |
| `r` | relevé détaillé des 200 premières durées | la structure fine des trames, à m'envoyer telle quelle |
| `f` | test du fil débranché | distingue une vraie liaison d'une entrée qui flotte (bruit) |
| `h` | poignée de main SRXL2, 115 200 puis 400 000 bauds, toutes les adresses | une réponse commençant par `A6` |
| `c` | liaison SRXL2 puis trames de commande pendant 5 s | la télémétrie, qui n'arrive qu'une fois la liaison établie |
| `e` | écoute passive à 11 vitesses, dont 500 000 et 1 M | le variateur qui parlerait tout seul |
| `b` | « break » puis écoute | certains bus ne se réveillent qu'ainsi |
| `p` | test de liaison : tire la ligne au bas puis relâche | savoir si le fil atteint vraiment le variateur (une résistance de tirage la remonte) |

**L'écho.** Émission et réception partagent le même fil : tout ce que la sonde
envoie revient dans sa propre entrée. Depuis cette version, ces octets sont
filtrés et l'affichage ne montre que ce qui vient **vraiment du variateur**,
sous le mot `REPONSE`. Si tu vois `A6 CD 16 …`, c'est notre trame à nous.

Ordre conseillé : `a`, puis `f` (pour éliminer le bruit), puis `r`, puis `h`
et `c`.

**Attention au piège du bruit.** Une entrée d'ESP32 laissée en l'air capte
des milliers de fronts par seconde, qui ressemblent à du trafic. Une vraie
liaison série donne des durées toutes multiples du temps de bit (2 µs, 4 µs,
6 µs… à 500 000 bauds) ; le bruit donne des durées quelconques. C'est
exactement ce que montre la répartition affichée par `a`.

## 4. Quoi m'envoyer

Copie-colle simplement le texte du moniteur série, même s'il est vide, en
précisant la tension mesurée et l'option choisie pour la prise. S'il y a des
octets, j'en déduis la vitesse, la structure des trames et j'écris le
décodeur pour le firmware.

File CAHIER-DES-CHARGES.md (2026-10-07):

# TrimBox — Cahier des charges

**Version du document :** 3.0 — 4 octobre 2026
**Cible :** firmware **2.0-a16** (ESP32-S3), console web **1.7.18**, script radio
`trmbox.lua` **2.3**.
**Remplace :** les anciens `CAHIER-DES-CHARGES.md` (v1, carte XIAO nRF52840) et
`CAHIER-DES-CHARGES-V2.md` (v2). Ce document est **autonome** : il ne décrit que
la version ESP32-S3 et se suffit à lui-même. La carte XIAO n'est plus suivie.
Les anciens renvois « v1 §x » et « v2 §y » encore présents dans des historiques
se convertissent avec l'annexe A.

---

## 0. Comment utiliser ce document

Ordre de lecture pour un assistant de code (ou un humain qui reprend le projet) :

1. **§1 à §3** : contexte, matériel, protocole. Tout en dépend.
2. **§12 (pièges connus)** : à fournir **systématiquement**, quel que soit le
   module travaillé. Chaque point a coûté au moins un cycle de débogage.
3. Le chapitre du module concerné : §4 firmware, §5 radio CRSF, §6 Wi-Fi et
   Bluetooth, §7 mise à jour, §8 console, §9 script Lua, §10 compilation.

> ⚠️ **Les valeurs numériques ne sont pas indicatives.** Chaque seuil, offset et
> constante a été fixé par mesure ou par contrainte matérielle. Les modifier
> sans raison casse le système, souvent sans bruit (données fausses plutôt que
> plantage visible).

**Règles dures** (rappelées en §8.13, §9 et §12) :

- Console : ne **jamais** modifier `distM`, `feed`, `anal.pts` / `anal.scr`, ni
  la chaîne de filtrage (`despike`, `despikeSpeed`, `plausible`, `gStats`,
  `pathLength`). Valider toute modification en **exécutant** la page
  (`tests/web`), pas par une simple vérification de syntaxe.
- Console : incrémenter `CONSOLE_VER` à **chaque** modification, puis
  `python3 tools/embed_console.py`.
- Script Lua : **jamais** `table.*` ni `ipairs` (§12.22).
- Firmware : `trimbox_s3/partitions.csv` ne change **jamais** dans une mise à
  jour par Wi-Fi (§7).
- Le module ne pilote **jamais** la voiture (§12.9).
- Langue du projet : français, commentaires du code compris.

Les éléments marqués **[À VALIDER]** n'ont pas encore été vérifiés sur le
matériel : le banc correspondant (§11.2) doit passer avant de bâtir dessus.

---

## 1. Contexte et objectifs

### 1.1 Objet

TrimBox est un **enregistreur de télémétrie GPS (25 Hz) et inertielle
pour voitures radiocommandées**, construit autour d'un **ESP32-S3**. Il :

- enregistre de façon autonome sur sa flash interne de 16 Mo, sans téléphone ;
- **chronomètre les tours dans le module**, à 25 Hz, avec des lignes posées
  **depuis la radio** ;
- envoie le chrono, l'état et la position à la radio **RadioMaster MT12**
  (télémétrie CRSF / ExpressLRS), qui affiche et **annonce les temps à voix
  haute** grâce à un script Lua ;
- se pilote et s'analyse depuis une **console web**, par Bluetooth (page
  GitHub) ou par le **Wi-Fi du module** (console intégrée au firmware, iPhone
  compris, sans Internet) ;
- se met à jour **par Wi-Fi depuis un téléphone**, avec retour automatique à la
  version précédente si la nouvelle échoue.

### 1.2 Livrables

| Livrable | Emplacement | Rôle |
|---|---|---|
| Firmware | `trimbox_s3/` (croquis Arduino) | Acquisition, stockage, chrono, CRSF, Bluetooth, Wi-Fi, OTA |
| Console web | `index.html` | Pilotage, téléchargement, analyse, mise à jour |
| Script radio | `lua/trmbox.lua` | Écran de télémétrie de la MT12, annonces, pose de ligne |
| Chaîne de compilation | `.github/workflows/build-s3.yml` | Tests et compilation en ligne, sans PC |
| Documentation matérielle | `docs/` | Schéma de câblage, boîtier imprimé 3D |
| Outils | `tools/` | Intégration de la console, génération du schéma et du boîtier, voix, sondes |
| Bancs de test | `tests/` | Natif (g++), navigateur, Lua, émulateur QEMU |

Fichiers annexes : `trimbox-sw.js` (service worker, optionnel),
`trimbox-diy-console-demo.html` (redirection des anciens liens vers la démo),
`trimbox-etat-projet.json` (état du projet pour reprendre avec une IA).

### 1.3 Contraintes fondamentales

- **Console sans dépendance** : un seul fichier HTML, sans CDN, sans framework.
  Elle doit fonctionner au bord d'une piste sans réseau. Seule exception
  assumée : les tuiles satellite.
- **Développement sans PC** : édition, compilation et récupération du firmware
  depuis un téléphone (GitHub Actions). Le PC ne sert qu'au **premier** flash.
- **Robustesse à la coupure d'alimentation** : une batterie arrachée en pleine
  session ne corrompt ni les données ni la configuration (§4.5).
- **La radio de commande passe avant tout** : le module ne pilote rien, et ses
  émetteurs 2,4 GHz (Wi-Fi, Bluetooth) se taisent quand la voiture roule (§6).
- **Pas de compatibilité RaceBox** : le *format de trame* en est hérité (§3.1),
  aucune contrainte applicative n'est maintenue.

### 1.4 Hors périmètre

- Pilotage des servos ou de l'ESC par le module : **interdit** (§12.9).
- Télémétrie de l'ESC XC-E8 : impossible, sa prise X-Bus est une entrée (§13).
- Application mobile native, cloud, comptes utilisateurs.

### 1.5 État d'avancement (4 octobre 2026)

| Sujet | État |
|---|---|
| Firmware 2.0-a16 | Écrit, testé sur PC, dans un navigateur et sous émulateur ; compile (1,26 Mo, 62 % de la partition) |
| GPS sur la carte | ✅ fix 3D, 13 satellites, ~20 Hz |
| IMU | ✅ capteur validé avec `tools/imu_test` (\|a\| = 0,99 g) ; à revérifier dans le firmware complet |
| Script Lua sur la MT12 | ✅ affichage, tours, annonces vocales, accusés de pose ; ✅ mixage CH8 configuré |
| Bluetooth et Wi-Fi réels, roulage | **[À VALIDER]** bancs §11.2 |
| Télémétrie de l'ESC | ❌ abandonnée (§13) |

---

## 2. Matériel

### 2.1 Nomenclature

| Élément | Référence | Remarque |
|---|---|---|
| Carte | **ESP32-S3-DevKitC-1, module WROOM-1-N16R8** | 16 Mo de flash, 8 Mo de PSRAM octale. Deux prises USB-C : **« USB »** (natif, à utiliser) et « UART » (pont série) |
| Centrale inertielle | **LSM6DS3 / LSM6DS3TR-C**, module générique I2C | Adresse **0x6A ou 0x6B** (broche SDO/SA0), détection automatique. Identifiants acceptés : 0x69, 0x6A, 0x6B, 0x6C. **±16 g** obligatoire (§2.5). Alternative ±32 g : LSM6DSO32 (§12.17) |
| GNSS | **HGLRC M100 Mini** (u-blox M10) | Alimenté en 5 V, signaux 3,3 V. Ne garde pas ses réglages : configuration **renvoyée à chaque démarrage** (§4.8) |
| Récepteur | **RadioMaster ER5C-i** (ExpressLRS 2,4 GHz) | Sorties 2 et 3 en CRSF série (§5.1) |
| Radio | **RadioMaster MT12** (EdgeTX) | Script `trmbox.lua` (§9) |
| ESC | **XC-E8** | **Non relié** au module (§13). Son BEC alimente le récepteur et le régulateur |
| Alimentation | Régulateur abaisseur **5 V, ≥ 1 A** (ex. Pololu D24V10F5) | Alimenté par le BEC (6,0 à 8,4 V) |

### 2.2 Alimentation

- Le module est alimenté par le **BEC de l'ESC** (6,0 à 8,4 V) via un
  **régulateur abaisseur 5 V**, qui alimente la carte (broche 5V) et le GNSS.
  Le régulateur 3,3 V de la carte alimente l'IMU.
- Le BEC ne va **jamais** directement sur la broche 5V de la carte (§12.18).
- Au banc, l'USB de la carte alimente tout ; ne pas cumuler USB et régulateur
  sans vérifier le schéma de la carte (retour de courant vers l'USB).
- Conséquence acceptée : le module ne fonctionne que batterie de la voiture
  branchée. L'octet batterie du message de données (offset 67) vaut **toujours
  0** ; la tension de la batterie de propulsion s'affiche **sur la radio**,
  par le capteur de tension du récepteur (§9).
- `GPS_EN` (GPIO 10) peut commander le 5 V du GNSS par un interrupteur de
  charge ; sans lui, le GPS reste alimenté, sans conséquence.

### 2.3 Brochage

```
Fonction        GPIO   Périphérique       Remarque
GNSS RX         18     UART1              ← TX du module GNSS
GNSS TX         17     UART1              → RX du module GNSS
GPS_EN          10     sortie             Commande d'alimentation du GNSS (facultative)
CRSF RX         16     UART2  420000 b    ← TX du récepteur (voies)
CRSF TX         15     UART2  420000 b    → RX du récepteur (télémétrie)
IMU SDA          8     I2C0
IMU SCL          9     I2C0
IMU INT1         7     entrée             (réservée)
LED          48 / 38   sortie             DEL RGB : GPIO 48 sur DevKitC-1 v1.0, 38 sur v1.1
BOUTON           0     entrée             Bouton BOOT (appui long : Wi-Fi, §6.2)
(libres)       5, 6    —                  ex-X-Bus, objectif abandonné (§13)
Journal série   USB    CDC natif          115 200 bauds, prise « USB »
```

**Broches interdites** (§12.11) : 35, 36, 37 (PSRAM octale), 19 et 20 (USB),
0, 3, 45, 46 en sortie (lues au démarrage). Entrées analogiques :
**exclusivement l'ADC1** (GPIO 1 à 10), l'ADC2 étant inutilisable Wi-Fi actif.

Tout signal de niveau inconnu est présumé à 5 V : l'ESP32-S3 n'est **pas**
tolérant au 5 V (§12.14). TX et RX se **croisent** (TX du module → RX de la
carte). Masse commune entre tous les éléments.

Schéma : `docs/cablage-trimbox-s3.svg` / `.pdf`, régénéré par
`tools/gen_cablage.py`.

### 2.4 Mémoire flash et partitions

Table de partitions `trimbox_s3/partitions.csv` (**ne jamais la modifier** dans
une mise à jour Wi-Fi : elle n'est réécrite que par un flash câblé) :

```
# Nom     Type  Sous-type  Adresse    Taille
nvs       data  nvs        0x9000     0x5000
otadata   data  ota        0xE000     0x2000
app0      app   ota_0      0x10000    0x200000    2 Mo
app1      app   ota_1      0x210000   0x200000    2 Mo
cfg       data  0x40       0x410000   0x4000      config A/B + lignes A/B (4 × 4 Ko)
log       data  0x41       0x414000   0xBEC000    journal, 12 500 992 octets
```

- Capacité : `12 500 992 / 81` = **154 333 emplacements**.
- Autonomie : **01h42min à 25 Hz**, 02h08min à 20 Hz, 04h17min à 10 Hz,
  08h34min à 5 Hz, 42h52min à 1 Hz (durées arrondies à la minute inférieure,
  format `00h00min`).
- Les événements de chrono (type `0x29`) prennent un emplacement par
  franchissement : négligeable.
- Firmware actuel : 1,26 Mo sur 2 Mo. Au-delà de **1,8 Mo**, le signaler plutôt
  que de réduire le journal en silence.

### 2.5 Limites physiques

- **Accéléromètre : ±16 g obligatoire.** À ±8 g, les atterrissages de saut
  saturent les trois axes à 7,99 g en même temps, avec des valeurs qui
  *semblent* plausibles (§12.8).
- **Gyroscope** : ±2000 °/s.
- **Précision GPS** : 30 cm à 1 m. Suffisant pour le chrono et les vitesses,
  insuffisant pour comparer des trajectoires au centimètre.
- **Bruit à l'arrêt** : une voiture posée « dérive » de 1 à 3 m (§4.10).

---

## 3. Protocole console

### 3.1 Origine et statut

Le format de trame dérive de la documentation du protocole BLE RaceBox
(révision 8). Il est **conservé tel quel** car la console s'appuie dessus, avec
des extensions maison (`FF F0` à `FF F3`, `FF 28` / `FF 29`). Aucune
compatibilité avec l'application RaceBox officielle n'est recherchée.

### 3.2 Transports

| Transport | Disponibilité | Notes |
|---|---|---|
| **Bluetooth** (service Nordic UART) | Voiture à l'arrêt (§6.3) | Console GitHub Pages, Chrome Android ou ordinateur |
| **WebSocket** `ws://192.168.4.1/ws` | Point d'accès Wi-Fi allumé (§6.2) | **Mêmes trames binaires** `B5 62…`, une trame ou un fragment par message. Prioritaire sur le Bluetooth |

Service Nordic UART :

```
Service  6E400001-B5A3-F393-E0A9-E50E24DCCA9E
RX       6E400002-B5A3-F393-E0A9-E50E24DCCA9E   écriture       (console → module)
TX       6E400003-B5A3-F393-E0A9-E50E24DCCA9E   notification   (module → console)
```

Service Device Information (`0x180A`) : modèle `2A24` (`TrimBox`), série
`2A25` (dérivée de l'adresse MAC), firmware `2A26`, matériel `2A27`, fabricant
`2A29`. **Le nom annoncé commence par `TrimBox`** : c'est le filtre de la
console. MTU demandé : 247. Écritures acceptées jusqu'à 512 octets (§12.2).

**Une seule console à la fois** reçoit le flux : quand un WebSocket est ouvert,
la file d'émission unique (§4.2) part vers lui ; un nouveau WebSocket remplace
l'ancien.

### 3.3 Structure de trame

```
 Octet  0     1     2       3     4-5            6...      n-2   n-1
       0xB5  0x62  classe  id    longueur LE    charge    ckA   ckB
```

Classe : toujours `0xFF`. Somme de contrôle **Fletcher-8** sur classe, id,
longueur et charge (pas sur les octets de synchronisation) :

```c
ckA = ckB = 0;
pour chaque octet o de [classe, id, len_lo, len_hi, charge...] :
    ckA = (ckA + o) & 0xFF;
    ckB = (ckB + ckA) & 0xFF;
```

Tous les entiers du protocole sont en **little-endian** (à l'inverse du CRSF,
§12.12).

### 3.4 Table des messages

| Classe/ID | Sens | Long. | Rôle |
|---|---|---|---|
| `FF 01` | → console | 80 | Données en direct (§3.5) |
| `FF 02` | → console | 2 | ACK : classe, id acquittés |
| `FF 03` | → console | 2 | NACK |
| `FF 21` | → console | 80 | Enregistrement mémoire (même format que `FF 01`) |
| `FF 22` | ↔ | 0 / 12 | État mémoire (§3.7) |
| `FF 23` | ↔ | 0 / 1 / 4 | Téléchargement (§3.12) |
| `FF 24` | ↔ | 0 / 1 | Effacement : démarrer / progression en % |
| `FF 25` | ↔ | 0 / 12 | Configuration d'enregistrement (§3.6) |
| `FF 26` | → console | 12 | Changement d'état d'enregistrement |
| `FF 27` | ↔ | 0 / 3 | Configuration du récepteur GNSS |
| `FF 28` | → console | 80 | **Réservé** (lot ESC, §13) : jamais émis |
| `FF 29` | → console | 80 | Événement de chrono (§3.11), en téléchargement seulement |
| `FF 30` | ↔ | 4 / 0 | Déverrouillage mémoire |
| `FF F0` | ↔ | 0 / var. | Identification du firmware (§3.8) |
| `FF F1` | ↔ | 0 / 28 | Lignes du module (§3.9) |
| `FF F2` | ↔ | 0 / 1 → 4 | Wi-Fi (§3.10) |
| `FF F3` | ↔ | 0 / 80 → 17 | Nom du véhicule et mot de passe Wi-Fi (§3.13, depuis 2.0-a15) |

Longueurs attendues par la console (table `EXPECT_LEN`, §8.3) :
`{0x01:80, 0x02:2, 0x03:2, 0x21:80, 0x22:12, 0x26:12, 0x28:80, 0x29:80, 0xF3:17}`.

### 3.5 Message de données (80 octets)

```
 0  u32  iTOW (ms)              40  u32  précision horizontale (mm)
 4  u16  année                  44  u32  précision verticale (mm)
 6  u8   mois                   48  i32  vitesse sol (mm/s)
 7  u8   jour                   52  i32  cap (deg × 1e5)
 8  u8   heure                  56  u32  précision vitesse (mm/s)
 9  u8   minute                 60  u32  précision cap
10  u8   seconde                64  u16  pDOP (× 100)
11  u8   drapeaux validité      66  u8   drapeaux lat/lon
12  u32  précision temps (ns)   67  u8   batterie : toujours 0 (§2.2)
16  i32  nanosecondes           68  i16  accél. X (milli-g)
20  u8   type de fix            70  i16  accél. Y (milli-g)
21  u8   drapeaux de fix        72  i16  accél. Z (milli-g)
22  u8   drapeaux date/heure    74  i16  gyro X (centi-deg/s)
23  u8   nombre de satellites   76  i16  gyro Y (centi-deg/s)
24  i32  longitude (deg × 1e7)  78  i16  gyro Z (centi-deg/s)
28  i32  latitude (deg × 1e7)
32  i32  altitude WGS84 (mm)
36  i32  altitude MSL (mm)
```

### 3.6 Configuration d'enregistrement `FF 25` (12 octets)

```
0  u8   activation (0 = arrêt, 1 = marche)
1  u8   cadence : 0=25 Hz  1=10 Hz  2=5 Hz  3=1 Hz  4=20 Hz
2  u8   drapeaux de filtre
3  u8   réservé
4  u16  seuil de vitesse « à l'arrêt » (mm/s)
6  u16  délai avant pause / fermeture à l'arrêt (s)
8  u16  délai avant pause sans fix (s)
10 u16  délai avant extinction automatique (s)
```

| Bit | Valeur | Filtre |
|---|---|---|
| 0 | `0x01` | Attendre un fix 3D avant de stocker |
| 1 | `0x02` | Suspendre à l'arrêt |
| 2 | `0x04` | Suspendre sans signal GPS |
| 3 | `0x08` | Éteindre après inactivité |
| 4 | `0x10` | Ne pas éteindre avant d'avoir enregistré au moins un point |
| 5 | `0x20` | **Démarrer et arrêter tout seul** (au roulage, §4.6) |

Valeurs par défaut : 25 Hz, `flags = 0x3F` (tout actif, automatique compris),
seuil 1389 mm/s (5 km/h), 30 s, 30 s, 300 s.

### 3.7 État mémoire `FF 22` (réponse, 12 octets)

```
0  u8   enregistrement en cours (0/1)
1  u8   taux de remplissage (%)
2  u8   drapeaux de sécurité (bit 0 = mémoire verrouillée)
3  u8   réservé
4  u32  emplacements utilisés
8  u32  capacité totale (154 333)
```

La console calcule les durées affichées à partir de cette capacité **réelle**,
jamais de valeurs écrites en dur.

### 3.8 Identification `FF F0`

Requête vide, réponse ASCII, champs séparés par `|` :

```
MODÈLE|VERSION|DATE_COMPILATION|PLAGE_G|PSEUDO
TrimBox|2.0-a15|Oct  4 2026 23:30:12|16|Buggy 1
```

- La **version** décide côté console des fonctions du firmware S3 : à partir
  de la version 2 (ou si le modèle contient `S3`, nom annoncé par les versions
  2.0-a1 à 2.0-a13 : « TrimBox DIY S3 »), le téléchargement demande les
  emplacements `0x29` et la console lit les lignes (`FF F1`).
- L'**empreinte de compilation** permet à la console de vérifier, après une
  mise à jour, quelle version tourne réellement (§7).
- Un appareil tiers répond NACK : la console traite ce cas sans erreur.

### 3.9 Lignes du module `FF F1`

Requête vide → réponse de 28 octets ; écriture de 28 octets → ACK.

```
0  u8   version (1)
1  u8   mode : 0 aucune, 1 circuit, 2 dragster (déduit des lignes posées)
2  u8   voie de commande CRSF (1 à 16, défaut 8)
3  u8   réservé
4  i32  départ : latitude (deg × 1e7)
8  i32  départ : longitude (deg × 1e7)
12 i32  départ : cap (deg × 1e5, 0 = nord, sens horaire)
16 i32  arrivée : latitude
20 i32  arrivée : longitude
24 i32  arrivée : cap
```

Une ligne absente a latitude et longitude à 0. Le centre de la ligne est le
point donné ; la ligne est perpendiculaire au cap, demi-longueur 4 m.

### 3.10 Wi-Fi `FF F2`

- Requête vide → 4 octets : `[allumé, automatique, nb d'appareils, console WebSocket connectée]`.
- `0` : couper et désactiver l'automatique ; `1` : allumer maintenant (NACK si
  la voiture roule) ; `2` : automatique seul.

### 3.11 Emplacements mémoire

Chaque emplacement fait **81 octets** : `[type][80 octets]`.

| Type | Contenu |
|---|---|
| `0x21` | Données (format §3.5) |
| `0x26` | Changement d'état : `[0]` état, `[1]` raison, `[4]` u32 iTOW, `[8]` u32 nb de points |
| `0x28` | Réservé (lot ESC, §13) : jamais écrit |
| `0x29` | Événement de chrono, écrit **seulement en enregistrement** : `[0]` u32 iTOW (interpolé pour un passage), `[4]` u8 ligne (0 départ, 1 arrivée), `[5]` u8 nature (0 passage, 1 tour, 2 parcours, 3 chrono intermédiaire), `[6]` u16 n°, `[8]` u32 temps (ms ; pour un chrono intermédiaire : depuis le départ), `[12]` u8 type de chrono (0 vitesse, 1 distance), `[14]` u16 valeur (km/h ou m) ; reste à zéro |
| `0x00` | Bourrage (emplacement douteux après un effacement interrompu, §4.3) |
| `0xFF` | Libre |

### 3.12 Séquences

**Téléchargement.** La console envoie `FF 23` → le module répond `FF 23`
(4 octets : nombre d'emplacements à parcourir, progression indicative) → flux
de `FF 21` et `FF 26` (et `FF 29` si demandé) → `FF 02` (ACK) final. Les
données en direct sont suspendues pendant l'opération.

| Charge de `FF 23` | Sens |
|---|---|
| vide | téléchargement des types `0x21` et `0x26` seulement |
| 1 octet, bit 1 (`0x02`), aucun téléchargement en cours | téléchargement **avec** les emplacements v2 (`0x28`, `0x29`) |
| 1 octet `0x00`, téléchargement en cours | annulation |

Les emplacements `0x21` invalides (§4.5) sont écartés et comptés (journal série
en fin de téléchargement).

**Effacement.** La console envoie `FF 24` → notifications `FF 24` (1 octet : %)
→ `FF 02` final. Refusé pendant un enregistrement ou un téléchargement ; une
fois lancé, **non annulable** (§12.4).

### 3.13 Véhicule et point d'accès `FF F3` (depuis 2.0-a15)

- Requête vide → **17 octets** : `[0..15]` nom du véhicule (ASCII, complété de
  zéros), `[16]` drapeaux (bit 0 : mot de passe Wi-Fi personnalisé). Le mot de
  passe n'est **jamais** renvoyé.
- Modification → **80 octets** : `[0]` masque (bit 0 nom, bit 1 mot de passe),
  `[1..16]` nom, `[17..79]` mot de passe (champs complétés de zéros ; un champ
  hors masque est ignoré). Règles (`core/ident`, identiques dans la console) :
  nom de **1 à 16** caractères parmi lettres sans accent, chiffres, espace (un
  seul, pas aux extrémités), `-`, `_`, `.` ; mot de passe WPA2 de **8 à 63**
  caractères ASCII imprimables.
- **NACK** si la valeur est invalide, si l'enregistrement n'est pas arrêté, si
  la voiture roule, pendant un téléchargement ou un effacement, ou tant
  qu'une nouvelle version est en validation (§7 : le redémarrage l'annulerait).
- Sinon : enregistrement en **NVS** (espace `trimbox`, clés `name` et `pass` ;
  la partition `cfg` est pleine et la table de partitions ne change jamais),
  **ACK**, puis **redémarrage 1,5 s plus tard**. Le module repart sous
  `TrimBox-<nom>` (Wi-Fi, espaces → `-`) et `TrimBox <nom>` (Bluetooth,
  modèle et préfixe filtré par la console inchangés), avec le nouveau mot de
  passe. `FF F0` annonce le nouveau nom.
- Valeurs par défaut (NVS vide ou invalide) : `DEVICE_NICKNAME` et `WIFI_PASS`
  de `config.h`. Mot de passe oublié : touche **`x`** du port série (retour
  aux valeurs d'origine), ou modification par la console en **Bluetooth**.

---

## 4. Firmware

### 4.1 Architecture

- Croquis Arduino `trimbox_s3/` ; `trimbox_s3.ino` n'appelle que
  `app::setup()` et `app::loop()`.
- `src/core/` : logique **sans matériel**, compilée et testée sur PC
  (protocoles TrimBox, UBX, CRSF ; chrono ; automate d'enregistrement ; pose de
  ligne ; configuration A/B ; maintien à l'arrêt ; radios de la console ;
  serveur HTTP/WebSocket ; contrôles de mise à jour).
- `src/hw/` : pilotes (GNSS, IMU, mémoire, Bluetooth, Wi-Fi, radio, OTA).
- `src/config.h` : réglages et brochage (§4.12).
- `src/console_gz.h` : console compressée, **générée** par
  `tools/embed_console.py` (ne pas éditer).

**Boucle unique, non bloquante**, sur le cœur 1, protocole d'abord :

```
1  commandes série
2  réception (Bluetooth, WebSocket) et exécution des commandes
3  effacement progressif
4  téléchargement (alimente la file d'émission)
5  vidange de la file vers la console
6  (extinction : décidée par l'automate, à chaque époque GNSS)
7  IMU, GNSS (une époque → enregistrement, chrono, télémétrie), voie de commande CRSF
   radios de la console (§6), validation OTA, bouton, DEL
```

La pile NimBLE tourne sur le cœur 0 ; ses rappels se contentent de déposer les
octets reçus dans un tampon protégé. Un découpage en tâches n'apporterait rien :
une écriture en flash gèle **les deux cœurs** (§4.3).

Chien de garde de boucle (`enableLoopWDT`, 5 s) : la carte redémarre si la
boucle se fige ; aucune opération ne dure plus de 3 s (reconfiguration GNSS).

### 4.2 File d'émission unique — exigence critique

**Toutes** les trames sortantes, données en direct comprises, quel que soit le
transport (Bluetooth ou WebSocket), passent par **une seule file d'octets**
(`TXQ_SIZE` 4096 octets, tampon circulaire).

> Deux chemins de sortie concurrents permettent à un paquet de s'insérer au
> milieu d'une réponse fragmentée : le flux côté console est corrompu et la
> réponse rejetée (§12.2).

- Les données en direct ne sont empilées que s'il reste au moins
  `LIVE_RESERVE = 88 + 256` octets libres : une réponse de commande n'est
  jamais perdue faute de place. Le direct est **sacrifiable**, les réponses non.
- Vidange Bluetooth : jusqu'à 12 notifications par tour, de `MTU − 3` octets
  (plafond 244). Un `notify()` refusé laisse les octets dans la file, sans perte
  ni réordonnancement. Vidange WebSocket : jusqu'à 8 messages de 1024 octets.

### 4.3 Écriture en flash interne

L'écriture ou l'effacement de la flash interne **suspend le cache
d'instructions** : tout code hors IRAM est gelé pendant l'opération.

- Écriture d'un emplacement (81 octets) : ~1 ms. Les FIFO matériels UART de 128
  octets couvrent ce délai, même à 420 000 bauds. Tampons logiciels : 4096 (GNSS),
  2048 (CRSF).
- Journal en **ajout linéaire** dans la partition `log`.
- **Aucun effacement pendant un enregistrement** : l'effacement porte sur la
  zone utilisée, d'un seul tenant, à la demande de la console.
- **Effacement à rebours**, du dernier secteur utilisé vers le premier :
  interrompu par une coupure, le journal reste contigu depuis l'adresse 0, et la
  recherche de fin par dichotomie reste valable.
- Au démarrage, la zone qui suit la fin du journal est contrôlée : si elle n'est
  pas vierge (effacement interrompu en plein secteur), les emplacements douteux
  sont marqués « bourrage » (`0x00`, obtenu en programmant des bits à 0, sans
  effacement) et le secteur suivant est effacé.

### 4.4 Configuration persistante — double exemplaire

Partition `cfg` : `RecConfig` A à l'offset 0, B à 4096 ; `LineConfig` A à 8192,
B à 12288. Écriture **en alternance** A puis B : une coupure pendant
l'effacement-réécriture d'un secteur laisse toujours un exemplaire valide.
Sérialisation **octet par octet** (jamais de `memcpy` de structure), CRC32 IEEE.
La NVS de l'ESP-IDF n'est **pas** utilisée pour ces structures.

`RecConfig` (28 octets) :

```
0  u32  magie 0x534D4252        12 u16  noFixInterval (s)
4  u8   version 2               14 u16  autoOffInterval (s)
5  u8   enabled                 16 u8   gnssDynModel (7)
6  u8   dataRate                17 u8   gnss3dSpeed
7  u8   flags (0x3F)            18 u8   gnssMinAcc (m, 0 = sans limite)
8  u16  statSpeed (mm/s)        19 u8   réservé
10 u16  statInterval (s)        20 u32  seq       24 u32  CRC32 des octets 0-23
```

`LineConfig` (40 octets) : magie `0x4C494E45` (« LINE »), puis la charge de
28 octets de §3.9 (version 1 en tête), `seq` à l'offset 32, CRC32 à l'offset 36.

Au démarrage : lire les deux exemplaires, valider magie + version + CRC, retenir
le plus récent par comparaison de `seq` tolérante au rebouclage
(`(int32_t)(b.seq − a.seq) > 0`). Relecture de contrôle après écriture.

### 4.5 Sécurité à la coupure d'alimentation

Quatre mécanismes, tous **obligatoires** :

1. **Double exemplaire** de la configuration (§4.4).
2. **Pas de reprise automatique** (`AUTO_RESUME_RECORDING 0`) : si la
   configuration indique « actif » au démarrage, la session précédente s'est mal
   terminée. Le module repart **à l'arrêt** (journal :
   « session précédente interrompue »), données téléchargeables.
   L'enregistrement automatique (§4.6), lui, reprend normalement au prochain
   roulage.
3. **Pas d'extinction trop tôt** : jamais avant `MIN_UPTIME_BEFORE_SLEEP_S`
   (120 s) après le démarrage, ni avant un premier point enregistré (`0x10`).
4. **Validation à la lecture** : un emplacement interrompu contient des octets
   restés à `0xFF`. Avant émission : `fixType ≤ 5`, `numSV ≤ 60`,
   `|lat| ≤ 900000000`, `|lon| ≤ 1800000000`, `0 ≤ gSpeed ≤ 140000000`.

Le GNSS reste allumé dès le démarrage (chrono radio et pose de ligne doivent
fonctionner sans enregistrement, §12.20).

### 4.6 Automate d'enregistrement

`core/recorder`, à chaque époque GNSS :

- **Attente de fix** (`0x01`) : rien n'est stocké avant un fix 3D.
- **Arrêt** (`0x02`) : vitesse sous `statSpeed` pendant `statInterval` →
  pause (seulement avec un fix valide).
- **Sans fix** (`0x04`) : absence de fix pendant `noFixInterval` → pause.
- **Reprise** : le passage pause → actif est notifié mais **pas stocké**
  (le passage actif → pause, lui, l'est).
- **Extinction** (`0x08`) : pause prolongée au-delà de `autoOffInterval` →
  veille profonde, réveil par le bouton BOOT.
- **Automatique** (`0x20`, actif par défaut) : l'enregistrement **s'ouvre**
  après 3 époques de suite au-dessus de `statSpeed` avec fix, et la session se
  **ferme** (état STOPPED, pas PAUSED) après `statInterval` à l'arrêt.
  **Un roulage = une session.** Les boutons de la console restent disponibles.

### 4.7 Commandes série (prise « USB », 115 200 bauds)

| Touche | Effet |
|---|---|
| `s` | Arrêt d'urgence de l'enregistrement |
| `r` | Démarrer l'enregistrement (essai sans téléphone) |
| `w` | Wi-Fi marche / arrêt (arrêt manuel : automatique désactivé, §6.2) |
| `i` | État : mémoire, enregistrement, configuration, lignes |
| `b` | Banc d'essai : cadence GNSS, IMU, CRSF (LQ, RSSI), Bluetooth (actif / coupé), Wi-Fi, partition du firmware (« EN VALIDATION » après une mise à jour) |
| `m` | Mesures de l'IMU en direct (10 lignes, mg et c°/s) |
| `z` | Configuration par défaut (données conservées) |
| `x` | Nom du véhicule et mot de passe Wi-Fi d'origine (`config.h`), puis redémarrage (§3.13) |
| `?` | Aide |

### 4.8 GNSS

- Recherche de la vitesse d'origine (38 400, 9 600, 115 200, 57 600, 230 400
  bauds), passage à **115 200**, configuration **renvoyée à chaque démarrage**.
- NMEA coupé, un **NAV-PVT** par solution.
- Cadence selon `dataRate`, **25 Hz** par défaut (`MAX_NAVIGATION_RATE 25`).
  Constellations : GPS + Galileo ; BeiDou, GLONASS, QZSS, SBAS coupés. Si la
  cadence n'est pas tenue avec Galileo, repli automatique sur le GPS seul
  **[À VALIDER]**.
- Modèle dynamique **7 (Airborne 2 g)** : une voiture RC dépasse 1 g en
  freinage et en virage, un modèle automobile lisserait ces valeurs.
- Filtres passe-bas de vitesse et de cap **désactivés** (`CFG-ODO-OUTLPVEL`,
  `CFG-ODO-OUTLPCOG`), maintien statique désactivé
  (`CFG-MOT-GNSSSPEED_THRS = 0`).

### 4.9 IMU

- Pilote maison (`hw/imu`) : sonde à 100 kHz puis 400 kHz, 5 essais,
  réinitialisation logicielle, relecture des registres, nouvel essai toutes les
  2 s si absente.
- ±16 g, ±2000 °/s, 416 Hz. `IMU_AVERAGE 1` : moyenne des échantillons sur la
  période GNSS (anti-repliement des vibrations) **[À VALIDER]** : comparer la
  détection du temps en l'air avec `IMU_AVERAGE 0`.
- Orientation selon le montage : `AXIS_*` dans `config.h`. L'IMU se visse
  **rigidement** au châssis, axes alignés sur la voiture.
- IMU absente : la console affiche des tirets (« IMU absente ») plutôt que des
  0,00 g.

### 4.10 Maintien à l'arrêt

`core/stillhold` (`STILL_HOLD 1`) : position figée (moyenne de 2 s) et vitesse
à **0** quand la voiture est immobile. Sans lui, le GPS « promène » une voiture
posée de 1 à 3 m et annonce une vitesse parasite : quelques dixièmes de km/h
sous un ciel dégagé, **jusqu'à 5 ou 6 km/h avec 4 ou 5 satellites** (essai du
07/10/2026 : affichage incohérent et faux départ de l'enregistrement
automatique). Toute la suite utilise la vitesse filtrée : affichage en direct,
enregistrement, démarrage automatique, Wi-Fi / Bluetooth, pose de ligne,
chronomètre.

- **IMU présente (cas normal) : elle tranche seule.** `hw/imu` mesure à chaque
  époque l'**agitation** (écart-type des échantillons, 3 axes combinés) ;
  les biais du capteur n'interviennent pas. Posée, une voiture reste à
  quelques mg et sous 1 °/s ; qui roule, qu'on pousse ou qu'on soulève, bien
  au-delà.
  - Entrée : calme (≤ 25 mg et ≤ 3 °/s) pendant **0,4 s**, quelle que soit la
    vitesse annoncée par le GPS.
  - Sortie : agitation franche (> 50 mg ou > 6 °/s) **2 époques de suite** (un
    choc isolé sur la table ne suffit pas), ou dès la première si le GPS
    confirme une vitesse significative.
  - Garde-fou (IMU décrochée ou mal fixée) : GPS au-dessus de 10 km/h et de
    3 × sAcc pendant 0,5 s → libéré.
- **IMU absente ou capteur figé : GPS seul**, avec des seuils qui tiennent
  compte de la précision de vitesse annoncée (sAcc) : entrée sous
  max(1,1 km/h ; 2 × sAcc), plafonné à 3,6 km/h, pendant 0,2 s ; sortie
  au-dessus de max(2,2 km/h ; 3 × sAcc), plafonné à 9 km/h.
- Dans les deux cas : éloignement de l'ancrage au-delà de max(4 m ; 3 × hAcc)
  → libéré (voiture déplacée).
- Réglage sur la voiture : touche série `m`, colonne « agitation » (doit
  rester « calme » voiture posée, moteur arrêté).
- `STILL_HOLD 0` pour enregistrer le GNSS brut.

### 4.11 DEL et bouton

| Couleur | Sens |
|---|---|
| rouge clignotant | GPS ou mémoire absents (normal au banc sans GPS) |
| rouge fixe | enregistrement en cours |
| orange | enregistrement en pause |
| vert clignotant | GPS calé, prêt |
| bleu fixe | console connectée |
| bleu clignotant | Wi-Fi ouvert, en attente du téléphone |

Les couleurs se superposent (rouge + bleu = violet). **Bouton BOOT, appui long
3 s** : Wi-Fi marche / arrêt.

### 4.12 Personnalisation (`config.h`)

| Réglage | Défaut | Rôle |
|---|---|---|
| `DEVICE_NICKNAME` | `"Buggy 1"` | Nom du véhicule **par défaut**, ≤ 16 caractères (§12.1) : `TrimBox Buggy 1` en Bluetooth, `TrimBox-Buggy-1` en Wi-Fi. Modifiable depuis la console (§3.13) |
| `FIRMWARE_VER` | `"2.0-a16"` | Version annoncée (`FF F0`, journal) |
| `WIFI_PASS` | `"trimbox-rc"` | Mot de passe WPA2 **par défaut** du point d'accès (8 à 63 caractères) ; à changer depuis la console (Réglages, §3.13) |
| `WIFI_AUTO_DEFAULT` | `1` | Wi-Fi automatique à l'arrêt |
| `WIFI_AUTO_ON_S` | `30` | Arrêt continu avant allumage du Wi-Fi |
| `BLE_AUTO_OFF` / `BLE_AUTO_ON_S` | `1` / `30` | Bluetooth coupé au roulage / rallumé après 30 s (§6.3) |
| `CRSF_LINE_CHANNEL_DEFAULT` | `8` | Voie de pose de ligne |
| `LINE_MIN_SPEED_MMS` / `LINE_ARM_WINDOW_MS` | `2000` / `10000` | Pose lancée au-dessus de 2 m/s ; sinon ligne armée 10 s (§5.5) |
| `PIN_LED_RGB` | `48` | **38** sur une DevKitC-1 v1.1 |
| `AXIS_*` | à plat, x vers l'avant | Orientation de l'IMU |
| `IMU_AVERAGE`, `STILL_HOLD` | `1`, `1` | §4.9, §4.10 |

Plusieurs voitures : un nom de véhicule différent par module suffit à les distinguer (Réglages de la console, sans recompiler).

---

## 5. Télémétrie radio CRSF

### 5.1 Liaison

- UART2, **420 000 bauds, 8N1, non inversé**, RX et TX séparés ; le module se
  comporte comme un **contrôleur de vol** vis-à-vis du récepteur.
- Récepteur ER5C-i (interface web, onglet *Model*) : sorties **2 et 3** en
  **Serial TX / Serial RX**, protocole CRSF ; direction sur la sortie 1 (CH1),
  ESC sur la sortie 4 (**CH2**), sortie 5 libre. Liaison validée sur la MT12.
- Croisement : TX du récepteur → GPIO 16, RX du récepteur ← GPIO 15. Masse
  commune. Aucun mixage de la MT12 n'est modifié, sauf CH8 (§9).

### 5.2 Format

```
[0xC8] [longueur] [type] [charge ...] [CRC8]
longueur = 1 (type) + taille(charge) + 1 (CRC)
CRC8 : polynôme 0xD5 (DVB-S2), sur type + charge
```

Entiers CRSF en **big-endian** : conversions par fonctions dédiées
(`put_be16`, `put_be32`…), jamais de `memcpy` de structure (§12.12).

### 5.3 Trames exploitées

**Reçues :** `0x16` voies RC (16 × 11 bits, lecture de la voie de commande) ;
`0x14` statistiques de liaison (RSSI, LQ : commande série `b`, non
enregistrées).

**Émises** — une trame juste après chaque trame de voies reçue, au plus une
toutes les 10 ms, en tourniquet :

| Type | Nom | Cadence | Contenu |
|---|---|---|---|
| `0x02` | GPS | 5 Hz | lat, lon (deg × 1e7), vitesse (km/h × 10), cap (deg × 100), altitude (m + 1000), satellites |
| `0x03` | Date et heure GPS | 1 Hz, dès que NAV-PVT les déclare valides et résolues (`valid & 0x07`) | int16 année, mois, jour, heure, minute, seconde (UTC), uint16 ms. Relayée par **ExpressLRS ≥ 4.1** (émetteur et récepteur), capteur `Date` sur EdgeTX |
| `0x21` | Mode de vol (texte) | à chaque événement, puis rappel d'état 1 Hz | Messages §5.4 |

`0x08` (batterie) n'est pas émis : la tension vient du récepteur. `0x0C` /
`0x0D` (régime, température) : sans objet tant qu'aucune mesure moteur n'existe.

### 5.4 Messages texte (trame `0x21`, capteur `FM`)

Canal de référence du chrono : transmis par tous les systèmes CRSF. **15
caractères ASCII au plus**, terminés par un octet nul. Temps formatés **dans le
module**, en millisecondes entières (jamais de virgule flottante dans la chaîne).

| Préfixe | Exemple | Sens |
|---|---|---|
| `L` | `L12 21.345+0.35` | Tour (ou parcours) 12 en 21,345 s, 0,35 s de plus que le meilleur **précédent** (négatif = nouveau meilleur). Écart omis au premier tour ou si le texte dépasse 15 caractères |
| `R` | `R 0-50 2.184` / `R 50m 3.012` | Dragster : chrono intermédiaire |
| `S` | `S REC C` | État (`REC` / `PAUSE` / `STOP` / `NOFIX`) puis lignes : `C` circuit, `D` dragster, `-` aucune |
| `K` | `K DEPART OK` / `K ARRIVEE OK` / `K ARME DEPART` / `K ARME ARRIVEE` / `K DELAI` / `K PAS DE FIX` / `K EFFACE` | Accusés de pose de ligne (§5.5). `K VIT FAIBLE` n'est plus émis ; le script le reconnaît encore |
| `W` | `W WIFI ON` / `W WIFI OFF` | Point d'accès de la console allumé / coupé |
| `U` | `U REDEMARRAGE` / `U VALIDATION` / `U MAJ OK` | Étapes d'une mise à jour (§7) |

**Un message à la fois.** Le récepteur ExpressLRS ne garde que le **dernier**
message en attente : deux messages envoyés coup sur coup, le premier est perdu.
D'où une **file** côté module : chaque message est tenu **seul 0,7 s**
(`CRSF_EVENT_HOLD_MS`), renvoyé toutes les 150 ms ; le rappel d'état `S` n'est
émis que file vide ; **un seul message par tour** (le script déduit le
meilleur tour) ; le script ne traite un message **qu'à son changement**. Réglage
ExpressLRS : *Telem Ratio* **1:16** ou plus fréquent.

### 5.5 Pose de ligne par la voie de commande

Mécanisme de référence : les voies passent toujours, quel que soit le système
radio. Voie `LineConfig.crsfChannel`, **CH8** par défaut.

- Neutre entre −30 % et +30 % ; **retour au neutre obligatoire** entre deux
  commandes (anti-rebond).
- **Haut (> +60 %) maintenu 0,5 s** : ligne de **départ** (ou ligne unique en
  circuit).
- **Bas (< −60 %) maintenu 0,5 s** : ligne d'**arrivée** (dragster).
- **Bas maintenu 3 s** : efface toutes les lignes (`K EFFACE`).
- **Mode déduit** : une ligne = circuit, départ + arrivée = dragster. Aucune
  commande de mode (l'état décide, pas le clic : §12.7).

**Voiture lancée** (≥ 2 m/s) : position **interpolée** entre les deux points
GNSS qui encadrent la commande, ligne **perpendiculaire au cap**, `K DEPART OK`.

**Voiture arrêtée** (`core/linearm`) : la position est mémorisée et la ligne
**armée** (`K ARME DEPART`). Le pilote démarre dans les **10 s**. Le cap de la
ligne est celui du départ : cap GNSS dès 3 m parcourus au-dessus de 7,2 km/h,
sinon direction ancrage → position après 6 m. La ligne est posée **0,5 m
devant** l'ancrage, puis les points du départ sont **rejoués** dans le chrono :
le départ arrêté compte (dragster : temps depuis l'arrêt ; circuit : début du
premier tour). Pas de départ dans le délai : `K DELAI`, rien n'est posé. Pas de
fix : `K PAS DE FIX`.

Dans les deux cas : demi-longueur **4 m** (comme la console), sauvegarde
immédiate dans `LineConfig` (survit à une coupure), lignes **gardées d'une
session à l'autre**.

### 5.6 Chronométrage embarqué

`core/lapcore` — **portage à l'identique** de l'algorithme de la console (§8.6),
mêmes constantes, **aucune « optimisation »** :

1. intersection segment/segment ;
2. proximité de l'ancrage : `halfM × 1,15` ;
3. sens : produit scalaire avec le cap de référence > 0,3 ;
4. déduplication : 1,5 s ;
5. temps interpolé entre les deux échantillons qui encadrent la traversée.

Modes **circuit** (un temps par tour) et **dragster** (un temps par parcours
départ → arrivée, plus chronos intermédiaires 0-30 / 0-50 / 0-80 km/h et
25 / 50 / 100 m, interpolés). Chaque événement est envoyé à la radio (§5.4) et,
en enregistrement, **stocké** (type `0x29`, §3.11). Firmware et console doivent
donner les mêmes temps **à 1 ms près** (§12.16, banc `console_check.js`).

---

## 6. Radios de la console : Wi-Fi et Bluetooth

### 6.1 Règle commune : coupées au roulage, rallumées à l'arrêt

`core/airgate` (testé sur PC), partagé par le Wi-Fi et le Bluetooth :

| Règle | Valeur |
|---|---|
| « Roule » | **3 solutions GNSS de suite** avec fix au-dessus de **7,2 km/h** (`WIFI_MOVE_MMS` 2000, `WIFI_MOVE_EPOCHS` 3 : 120 ms à 25 Hz) |
| « À l'arrêt » | sous **5 km/h** (`WIFI_STILL_MMS` 1389), **ou sans fix**, ou sans solution GNSS depuis 2 s |
| Coupure | **immédiate** dès que la voiture roule, **sans condition** (même forcée à la main) |
| Rallumage | après **30 s d'arrêt continu**, si l'automatique est actif |
| Entre 5 et 7,2 km/h | rien n'est coupé ; le compteur d'arrêt repart de zéro |

Cas limites :

- Wi-Fi coupé **à la main** (bouton, touche `w`, `FF F2` 0) : il ne revient plus
  seul jusqu'au prochain forçage ou redémarrage — mais il est toujours coupé en
  roulant.
- **Perte du GPS en roulant** : la voiture est réputée à l'arrêt (on ne roule
  pas en course sans GNSS) ; les radios reviennent après 30 s.

Motif : un émetteur 2,4 GHz à quelques centimètres du récepteur ExpressLRS peut
dégrader la liaison de commande (§12.10). La règle s'applique quel que soit le
système radio.

### 6.2 Point d'accès Wi-Fi

- SSID `TrimBox-<nom du véhicule>` (espaces → `-`), WPA2 (mot de passe de §3.13, `WIFI_PASS` par défaut), canal 6,
  **2 appareils** au plus, puissance **8,5 dBm** (portée d'un stand), adresse
  `192.168.4.1`.
- Juste allumé, le module est réputé à l'arrêt : le point d'accès apparaît
  **30 s** après la mise sous tension.
- **Portail captif** : un serveur DNS répond `192.168.4.1` à toute requête et
  toute autre adresse renvoie `302` vers la console ; le téléphone propose
  d'ouvrir la page.
- Forçage : appui long 3 s sur BOOT, touche `w`, ou `FF F2`. La radio est
  prévenue (`W WIFI ON` / `W WIFI OFF`).
- Pas de coupure « au démarrage d'un enregistrement » ni « sans client » :
  démarrer un enregistrement depuis la console Wi-Fi couperait sa propre
  réponse. Le mouvement suffit.

### 6.3 Bluetooth

- Actif **dès la mise sous tension**.
- Dès que la voiture roule : annonces arrêtées, console connectée
  **déconnectée**. Retour après `BLE_AUTO_ON_S` (30 s) d'arrêt.
- Pas de message radio (la file `FM` est réservée au chrono) ; état visible par
  la commande série `b` (« BLE actif » / « COUPÉ (la voiture roule) »).
- `BLE_AUTO_OFF 0` : Bluetooth permanent (comportement 2.0-a12).
- Conséquence acceptée : pas de données en direct par Bluetooth pendant le
  roulage ; la session se télécharge au stand.
- **[À VALIDER]** sur la carte (le Bluetooth n'est pas émulé).

### 6.4 Console embarquée

- `tools/embed_console.py` compresse `index.html` (gzip, horodatage nul :
  résultat reproductible) en `trimbox_s3/src/console_gz.h` (~56 Ko). La CI le
  régénère avant chaque compilation.
- Serveur HTTP + WebSocket **écrit pour le projet** (`core/httpws`), sans
  bibliothèque : compilé et testé sur PC avec de vraies sockets et un vrai
  navigateur (`tests/web`).
- `Cache-Control: no-cache` : une nouvelle console arrive avec le firmware.
- Pas de service worker (origine non HTTPS) ; `localStorage` fonctionne
  (thème et accent mémorisés **pour l'origine du module**).

---

## 7. Mise à jour du firmware par Wi-Fi (OTA)

- Voie normale : section **Mise à jour du firmware** de la console (visible en
  Wi-Fi uniquement). Secours : page minimale `GET /update`.
- `POST /update`, corps = le `.bin` applicatif brut (`Content-Length`
  obligatoire, `Expect: 100-continue` géré), transmis **au fil de l'eau** à la
  partition OTA inactive (effacement progressif) : aucune pause longue, aucune
  copie en RAM.
- **Conditions** (sinon refus, message renvoyé tel quel) : enregistrement
  arrêté, voiture à l'arrêt, ni téléchargement ni effacement en cours.
- **Contrôles** (`core/otacheck`) : octet magique `0xE9`, puce ESP32-S3
  (id 9), taille ≤ partition (le fichier « complet » de 16 Mo est refusé
  d'emblée), marque **`TRIMBOX-S3-FIRMWARE-MARK-v1`** présente dans l'image ;
  puis SHA-256 par `esp_ota_end`. En cas de refus, le corps est lu jusqu'au
  bout pour que le navigateur reçoive l'explication.
- Accepté : `esp_ota_set_boot_partition`, réponse `200`, redémarrage 1,5 s plus
  tard (`U REDEMARRAGE`).
- **Retour arrière** (`CONFIG_BOOTLOADER_APP_ROLLBACK_ENABLE`) : le core Arduino
  confirme d'office tout nouveau firmware ; `verifyRollbackLater()` est
  redéfinie pour reprendre la main. Confirmation après **autotest** (mémoire et
  configuration lues) **et 15 s** de fonctionnement (`OTA_VALIDATE_AFTER_S`) :
  `U VALIDATION` puis `U MAJ OK`. Plantage, gel de la boucle > 5 s ou coupure
  avant : retour automatique à la version précédente.
- La console compare l'empreinte de compilation (`FF F0`) avant et après :
  « nouvelle version active » ou « le module est revenu à la précédente ».
- **Premier flash** : toujours par câble, fichier complet à `0x0` (efface la
  mémoire d'enregistrement).
- `partitions.csv` ne change **jamais** par OTA.

---

## 8. Console web

### 8.1 Contraintes

- **Un seul fichier** `index.html`, autonome, sans bibliothèque : rendu en
  Canvas 2D natif.
- Bluetooth Web : origine **HTTPS** obligatoire (GitHub Pages). Console Wi-Fi :
  servie en `http:` par le module.
- Toutes les variables d'état sont déclarées **en tête de script** (§12.6).

### 8.2 Sources de données

Commutateur **Bluetooth / Wi-Fi / Démo**. Toutes les commandes passent par des
fonctions uniques (`doConnect`, `doDownload`…) qui se comportent selon la source
(`demoMode`, `wifiMode`). **Ne jamais réaffecter les gestionnaires
d'événements** pour changer de source.

- **Wi-Fi** : proposé seulement quand la page est servie par le module ; choisi
  et connecté automatiquement ; Bluetooth et Démo sont alors masqués ;
  reconnexion automatique toutes les 3 s tant que l'utilisateur n'a pas
  déconnecté (le point d'accès disparaît quand la voiture roule).
- **Démo** : simule un module S3 complet (direct 25 Hz, mémoire de 154 333
  points, trois sessions dont une ligne droite pour le dragster).

### 8.3 Réassemblage des trames (`feed`) — exigence critique

Le flux arrive fragmenté. Le réassembleur :

1. cherche `B5 62` ;
2. **valide la longueur annoncée** contre `EXPECT_LEN` (§3.4) : une longueur
   incohérente signale un faux départ → avancer de 2 octets ;
3. vérifie la somme de contrôle ;
4. **en cas d'échec, avance de 2 octets — jamais de la longueur annoncée.**

Le WebSocket réutilise `feed()` **sans modification**. Seule modification admise
de son entourage : la table `EXPECT_LEN`. C'est le bug le plus coûteux du projet
(§12.2) : 50 % de perte de données avant correction, 0,2 % après.

### 8.4 Filtrage des données

| Niveau | Règle | Motif |
|---|---|---|
| Plausibilité (`plausible`) | `|lat| ≤ 90`, `|lon| ≤ 180`, `0 ≤ vitesse < 500 km/h`, `fix ≤ 5`, `sats ≤ 60`, `|alt| < 10 000 m`, `|accél.| ≤ 20 g` | Une trame corrompue passe la somme de contrôle une fois sur 65 536 |
| Position (`despike`) | point à plus de **30 m** (`MAX_STEP_M`) du précédent **et** du suivant → supprimé | décrochages isolés du récepteur |
| Vitesse (`despikeSpeed`) | écart > **20 km/h** (`MAX_DV_KMH`) avec les deux voisins → moyenne des voisins | à 25 Hz, même 10 g ne font que 14 km/h en 40 ms |

Le seuil de 20 g est calibré pour ±16 g ; le passer à 35 g seulement si l'IMU
passe à ±32 g, et sur demande explicite (§12.17).

### 8.5 Analyse

- Statistiques de session : vitesses max / moyenne / min, distance, durée,
  accélération, freinage, latéral, vertical max / min, temps en l'air.
- **Temps en l'air** : `|az| < 0,35 g` pendant au moins **3 échantillons**
  (`MIN_AIR_SAMPLES`) ; sans ce seuil, les vibrations produisent des centaines
  de faux sauts. Ignoré sans IMU (0 g partout). Rapporté **au tour** quand une
  ligne est posée.
- **Survol du tracé** : agrégation de **tous les passages** au même endroit
  (nombre, vitesses, G) dans une infobulle.
- **Portion** : glisser sur le profil de vitesse isole une portion et ses
  statistiques.
- Session vide ou sans fix : explication affichée (nombre de points, de fix).
- **Comparaison** de sessions : tableau, vitesse en fonction de la distance,
  trajectoires superposées. Le profil est gradué en **mètres depuis le départ
  de chaque session** (une même abscisse = le même endroit du parcours ; la
  session la plus courte s'arrête avant). Le survol affiche la vitesse de
  chaque session au point visé. **Glisser** sur le profil sélectionne une
  portion [d0, d1] : tableau par session (durée avec écart au meilleur temps,
  distance, V max / moyenne / mini, accélération, freinage, latéral, vertical,
  temps en l'air, points ; « — » si la session s'arrête avant) et portion
  surlignée sur les trajectoires. Un appui sans glisser ou « Effacer » retire
  la sélection ; elle est conservée au redimensionnement et tant que les
  sessions comparées ne changent pas. Distances cumulées avec la règle de
  `pathLength` (saut > `MAX_STEP_M` ignoré). Le profil reste à sa place à
  l'écran quand le tableau apparaît (`overflow-anchor:none` + correction).

### 8.6 Chronométrage de la console

Modes **Circuit** (une ligne, un temps par tour) et **Dragster** (départ +
arrivée ; chaque départ est associé au premier franchissement de l'arrivée qui
le suit). Détection : intersection, proximité de l'ancrage (`halfM × 1,15`),
sens (> 0,3), déduplication 1,5 s, temps interpolé ; demi-longueur **4 m**.
Chronos intermédiaires configurables (vitesses, distances), interpolés. **Même
algorithme que le firmware** (§5.6, §12.16). Changer de mode efface les lignes.

### 8.7 Lignes et chronos du module

- À la connexion d'un module **S3**, la console lit `FF F1` ; les lignes sont
  posées **d'office** dans l'analyse si elles sont à moins de **30 m** du
  tracé (mode circuit ou dragster déduit du module). Bouton **« Lignes du
  module »** pour les relire. Elles restent connues après la coupure du Wi-Fi
  (oubliées en passant en démo).
- Ligne reconstruite par `makeLineAt(lat, lon, cap)`, même géométrie que
  `makeLine` (fonction commune `lineFrom`).
- Téléchargement depuis un module S3 : `FF 23` + `0x02`. Les emplacements
  `0x29` sont rattachés à leur session (celle du point qui les précède) et
  affichés dans l'encart **« Chronos du module »** : tours ou parcours au
  millième, chronos intermédiaires, et **écart** avec le calcul de la console
  sur le même tracé (quelques ms au plus).

### 8.8 Cartographie

- Projection **Web Mercator** normalisée [0, 1].
- **Zoom continu** ×1 à ×60 (`ZOOM_MAX`), ancré sous le curseur ; pincement au
  doigt ; cadrage minimal de 25 m (le bruit GPS d'une voiture posée n'est pas
  agrandi).
- Tuiles Esri `…/World_Imagery/MapServer/tile/{z}/{y}/{x}` (ordre **z/y/x**),
  niveau **plafonné à 19** (`MAX_TILE_Z`, §12.5). Attribution : « Esri, Maxar,
  Earthstar Geographics ».
- Sans Internet (Wi-Fi du module) : le fond satellite reste actif, un message
  l'explique et la console réessaie toutes les 10 s (les images passent par la
  4G du téléphone si Android y bascule ; ouvrir la console dans Chrome, pas dans
  la fenêtre de portail captif).

### 8.9 Exports et imports

| Format | Export | Import | Usage |
|---|---|---|---|
| **VBO** | ✅ | ✅ | RaceChrono Pro, Circuit Tools |
| **CSV** | ✅ | ✅ | Tableur |
| **GPX** | ✅ | ✅ | Cartographie |

Pièges du VBO : latitude / longitude en **minutes d'arc**, longitude **positive
vers l'ouest**, section `[column names]` en jetons courts
(`sats time lat long velocity heading height vert-vel LongAcc LatAcc`), temps
`HHMMSS.SS`. Un GPX ne transporte ni vitesse ni accélérations : reconstituées à
partir des positions. Aller-retour vérifié < 5 cm.

### 8.10 Interface

- **Thèmes** sombre (noir intégral `#000000`, économie OLED) et clair (`#F3EFFB`),
  bascule par bouton, préférence mémorisée (`localStorage`), choix initial :
  préférence enregistrée → système → sombre.
- **Couleur d'accent** au choix (bouton palette : 5 préréglages, couleur libre,
  « Par défaut »), mémorisée (`trimbox-accent`). Variantes dérivées
  (`--violet-glow`, `--violet-dim`, `--violet-rgb`) ; texte des boutons en noir
  si le blanc n'atteint pas 4,5:1. Couleurs d'état (ok / rec / warn) jamais
  modifiées. Variantes de texte assombries en thème clair (`--ok-text`…).
- Les canevas ne lisent pas les variables CSS : cache `THEME` rafraîchi à chaque
  changement de thème (`refreshTheme`), puis **redessin**.
- **Mise en page adaptative** :
  - téléphone (< 700 px) : une colonne ; sous 440 px, l'état de connexion passe
    sous le titre et les valeurs longues sont réduites ;
  - tablette (700 à 1099 px) : une colonne plus large ;
  - ordinateur (≥ 1100 px, depuis 1.7.14) : **toute la largeur de l'écran** et
    une **barre d'onglets** — *Appareil* (connexion, direct, mémoire),
    *Analyse* (carte et profil à gauche, chiffres et tours à droite ; message
    d'attente sans session), *Sessions* (ouverture de fichiers, liste en
    grille ; le bouton « Choisir des fichiers… » est aligné sur la ligne « Tout
    exporter », comparaison), *Réglages* (enregistrement autonome, véhicule et
    point d'accès, mise à jour,
    journal ouvert) — à côté du choix de la source. Dans un onglet, les
    panneaux sont des tuiles qui se partagent la ligne (`flex-wrap`) : la ligne
    est toujours remplie. Chaque panneau porte `data-pane`, `body[data-tab]`
    choisit l'onglet ; l'analyse d'une session ouvre l'onglet *Analyse*. Onglet
    mémorisé (sauf *Analyse*), flèches gauche / droite au clavier. La carte
    n'est jamais plus haute que l'écran.
  Les regroupements (`.colA`, `.colB`, `.anMain`, `.anStats`, `.anBoxes`) sont
  en `display:contents` sous 1100 px, l'ordre étant fixé par `order` : le
  téléphone et la tablette affichent tout, sans onglets, comme avant. Aucun
  défilement horizontal de 320 à 2560 px (vérifié par `tests/web`, qui vérifie
  aussi le contenu de chaque onglet).
- Les courbes (`#chart`, `#cmpChart`) adaptent leur résolution interne à leur
  taille affichée et à la densité de l'écran (`fitCanvas`, plafond ×2) ; textes
  et traits sont mis à l'échelle. Les conversions souris → canevas passent par
  le rapport largeur interne / largeur affichée.
- **Incrustations de la carte** (infobulle, échelle, crédit) : fond sombre
  **fixe** et couleurs **fixes**, indépendantes du thème et de l'accent
  (§12.24).
- En-tête : version de la console et version du firmware connecté.

### 8.11 PWA

Manifeste et icônes **en data URI** dans le HTML (installation manuelle sans
fichier annexe). Service worker `trimbox-sw.js` **optionnel**, à côté de la page
(GitHub Pages) : hors ligne et invite d'installation ; son gestionnaire `fetch`
doit être réellement fonctionnel.

### 8.12 Versionnage

Constante `CONSOLE_VER` (actuellement **1.7.18**), affichée dans l'en-tête,
incrémentée à **chaque** modification ; après `x.y.9`, passer à `x.y.10` (puis
selon la convention en cours). Sert d'indicateur de cache. Après toute
modification : `python3 tools/embed_console.py`.

### 8.13 Fonctions protégées

Trois corruptions par un LLM local, toutes présentées comme des
« optimisations », syntaxiquement plausibles, invisibles sans exécution.
**Interdiction de modifier** :

- `distM()` — projection équirectangulaire : les écarts sont en **degrés**,
  111320 / 110540 sont des mètres **par degré** ; ne jamais convertir en radians
  avant ; le `cos(latitude)` est indispensable.
- `anal.pts` et `anal.scr` — ne jamais les supprimer « pour libérer la
  mémoire » : carte, survol, tours et exports les relisent en continu.
- `despike()`, `despikeSpeed()`, `plausible()`, `gStats()`, `pathLength()` —
  seuils déterminés par mesure.
- `feed()` — en cas d'échec de somme de contrôle, avancer de 2 octets, jamais de
  la longueur annoncée.

---

## 9. Script Lua EdgeTX (MT12)

Fichier `lua/trmbox.lua` → carte SD `SCRIPTS/TELEMETRY/trmbox.lua` (**6
caractères** au plus : limite d'EdgeTX pour les écrans monochromes).
Écran 128 × 64. Mode d'emploi détaillé : `lua/LISEZMOI.md`.

- **Lecture** : capteur `FM` (`getValue`) et, si EdgeTX y dépose ces trames,
  file brute CRSF (`crossfireTelemetryPop`, trames `0x21`). `run()` et
  `background()` lisent tous les deux. Traitement **au changement** de message.
  Plus de 3 s sans message : « PAS DE LIAISON ».
- **Pages** : *Chrono* (dernier tour en grand, n°, écart, meilleur, tours
  précédents), *Machine* (vitesse filtrée sous 3 km/h, Vmax, satellites, LQ,
  RSSI, altitude, tension de la batterie lue sur le récepteur — capteurs
  `Batt`, `RxBt`, `VFAS`, `A1` — avec tension par élément, date et heure GPS en
  heure locale), *Lignes* (mode, actions, valeur réelle de CH8).
- **Touches** (événements virtuels) : molette = pages (sur *Lignes* : choix de
  l'action) ; ENT court = page suivante (sur *Lignes* : exécuter ; second appui
  pour confirmer l'effacement) ; ENT long sur *Chrono* = remise à zéro.
- **Pose de ligne** : le script écrit **GV9** pour les 9 modes de vol ; mixage
  **CH8 = source MAX, poids GV9, mode Ajouter** (`GV9 = 100` → CH8 = +100 %).
  Départ +100 pendant 0,6 s ; arrivée −100 pendant 0,6 s ; effacement −100
  pendant 3,2 s ; une commande à la fois. Si CH8 ne bouge pas pendant un envoi :
  « CH8 immobile : mixage ? ». Sans le script : un inter 3 positions sur CH8.
- **Voix** : à chaque tour, « meilleur tour » s'il y a lieu, le temps
  (`playNumber`, centièmes), puis l'écart avec le tour **précédent** (« plus »,
  « moins », « égal ») ; accusés de pose dits à voix haute. Les nombres viennent
  du pack vocal de la radio ; les **12 mots** (`meilleur`, `plus`, `moins`,
  `egal`, `depart`, `arrivee`, `efface`, `arme`, `delai`, `vitfaib`, `pasgps`,
  `refus`) de `SOUNDS/trimbox/` (ou `trmbox/`, `fr/trimbox/`), WAV 16 bits mono
  16 kHz, fournis dans `lua/SOUNDS/trimbox/` ; sans eux, des bips. Génération :
  `tools/sons/generer-voix.bat` (voix Azure du pack EdgeTX) ; mots
  supplémentaires à la demande : `tools/sons/generer-mot.bat`.
- **Heure** : capteur `Date` (trame `0x03`) convertie en heure locale
  (`TZ_OFFSET` 1, heure d'été européenne `TZ_EU_DST`).
- ⚠️ **Règle dure** : un script de télémétrie n'a **pas** la bibliothèque
  `table` (§12.22). Ni `table.*` ni `ipairs`. Restent sûrs : `string.*`,
  `math.*`, `type`, `tonumber`, `pairs` sur tables littérales locales.

Validé sur la MT12 : lecture de `FM`, touches, lisibilité, annonces vocales,
accusés de pose, mixage CH8. **[À VALIDER]** : pose de ligne à l'arrêt sur la
voiture, enregistrement automatique en roulage.

---

## 10. Compilation, tests et déploiement

### 10.1 Chaîne de compilation (GitHub Actions)

`.github/workflows/build-s3.yml`, déclenché à chaque envoi :

- arduino-cli, core **`esp32:esp32@3.3.12`** et **`NimBLE-Arduino@2.5.1`**,
  versions **figées**. Pas d'autre bibliothèque : GNSS et IMU ont des pilotes
  maison.
- FQBN `esp32:esp32:esp32s3:FlashSize=16M,PSRAM=opi,FlashMode=qio,USBMode=hwcdc,CDCOnBoot=cdc,PartitionScheme=no_fs`
  (un `partitions.csv` dans le dossier du croquis est prioritaire).
- Un seul `.ino` dans `trimbox_s3/` (vérifié par la CI).
- `tools/embed_console.py` avant chaque compilation.
- Artefacts : `firmware-s3-complet` (`trimbox_s3-complet.bin` à `0x0` +
  fichiers séparés), `firmware-s3-app` (`trimbox_s3-app.bin`, OTA, non
  compressé), `capture-console-wifi`.
- La compilation échoue si un test échoue.
- **Publication** (job `release`) : seulement sur `main` (envoi ou lancement
  manuel), après succès de **tous** les jobs (tests, compilation, console,
  émulateur). Crée la release GitHub `firmware-<FIRMWARE_VER>` (marquée
  « Latest ») avec `trimbox_s3-app.bin`, `trimbox_s3-complet.bin`, bootloader
  et partitions séparés, `index.html`, `trimbox-radio.zip` (`trmbox.lua`,
  `LISEZMOI.md`, `SOUNDS`) et `SHA256SUMS.txt`. Notes rédigées par
  `tools/release_notes.py` : versions firmware et console, commit, usage de
  chaque fichier, procédures de mise à jour et de premier flash, nouveautés
  (messages de commit depuis la release précédente), vérifications passées,
  empreintes SHA-256. Une version déjà publiée n'est **jamais écrasée** : pour
  publier, incrémenter `FIRMWARE_VER`.

Compilation hors CI : mêmes versions. Sans accès à `downloads.arduino.cc`,
l'outil `ctags` peut être remplacé par un script vide (le `.ino` ne déclare que
`setup()` et `loop()`) : `--build-property runtime.tools.ctags.path=<dossier>`.

### 10.2 Bancs automatisés

| Banc | Commande | Vérifie |
|---|---|---|
| Logique (g++) | `make -C tests/native` | protocoles, chrono (5 tours de 20,00 s, ligne en 4 endroits ; dragster à 6 m/s²), automate, pose de ligne, config A/B, maintien à l'arrêt, radios de la console, serveur web, contrôles OTA — ~2 500 vérifications |
| Chrono firmware = console | `node tests/native/console_check.js index.html tests/native/lap_cases.json` | mêmes trajets dans les deux implémentations, écart ≤ 1 ms ; ligne relue dans le module = ligne posée sur le tracé |
| Script Lua | `lua5.2 tests/lua/test_trmbox.lua lua/trmbox.lua` | messages, sons, impulsions GV9, affichage, file CRSF brute, dossiers de voix ; `table = nil` avant chargement |
| Console | `python3 tests/web/console_web_test.py tests/web/fakedev 8088 trimbox_s3-app.bin` | page servie gzip par le vrai serveur, Wi-Fi auto, direct 25 Hz, téléchargement + chronos du module, lignes `FF F1`, reconnexion, accent, mise à jour avec le vrai `.bin`, mise en page de 320 à 1440 px |
| Émulateur | `python3 tests/qemu/sim.py flash.bin` (`--lua`, `--arret`, `--reboot`) | GNSS 25 Hz, enregistrement, pose de ligne CH8 (par le vrai script), tours de 12,000 s sans perte côté radio, Wi-Fi coupé au roulage et rallumé à l'arrêt, coupure d'alimentation |
| Retour arrière | `python3 tests/qemu/ota_rollback.py merged.bin app.bin app_qui_plante.bin` | version saine conservée, version qui plante → retour sur `app0` (vrai chargeur) |

Pièges de l'émulateur : §12.19 (variante `-DTRIMBOX_QEMU`, jamais flashée).

### 10.3 Déploiement

1. **Dépôt GitHub** : tout le contenu, dossier `.github/` compris. L'onglet
   *Actions* compile et teste (10 à 15 min la première fois).
2. **GitHub Pages** (*Settings → Pages → `main`, `/ (root)`*) : console
   Bluetooth à `https://<pseudo>.github.io/<dépôt>/`. Noms de fichiers
   sensibles à la casse.
3. **Premier flash**, une fois, par câble, depuis un ordinateur :
   `trimbox_s3-complet.bin` à `0x0` avec https://espressif.github.io/esptool-js/,
   prise **USB** (si rien : BOOT maintenu + RST, relâcher BOOT).
4. **Ensuite** : `trimbox_s3-app.bin` par la console Wi-Fi (§7).
5. **Radio** : `trmbox.lua` dans `SCRIPTS/TELEMETRY/`, mots dans
   `SOUNDS/trimbox/`, mixage CH8, *Découvrir les capteurs*, écran de
   télémétrie → script `trmbox`.

---

## 11. Recette et bancs matériels

### 11.1 Critères d'acceptation

Firmware :

- [ ] Au démarrage, le journal affiche marque, pseudo, version (2.0-a16),
      empreinte de compilation, `mémoire : n / 154333`.
- [ ] `b` : GNSS 25 Hz dehors, IMU présente, CRSF « liaison OK », BLE actif.
- [ ] Un roulage ouvre une session et la ferme 30 s après l'arrêt.
- [ ] Voiture posée (même avec peu de satellites) : vitesse affichée 0,0 km/h,
      position figée, aucun enregistrement automatique ; `m` : « calme ».
- [ ] **Arrachement** : couper l'alimentation en pleine session. Au
      redémarrage, le module est joignable, à l'arrêt, données intactes.
- [ ] Le téléchargement signale les emplacements corrompus écartés.
- [ ] Wi-Fi et Bluetooth coupés en roulant, revenus 30 s après l'arrêt.
- [ ] Mise à jour Wi-Fi acceptée ; une version qui plante revient seule à la
      précédente.

Console :

- [ ] Aucune trame rejetée lors d'un téléchargement complet.
- [ ] Aucune vitesse > 150 km/h, aucun « aller-retour » sur le tracé.
- [ ] Export VBO lu par Circuit Tools au bon endroit du globe ; aller-retour
      export → import < 5 cm.
- [ ] Lignes du module posées d'office ; chronos du module = chronos console
      à quelques ms.
- [ ] Les deux thèmes lisibles, infobulle comprise ; pas de défilement
      horizontal sur téléphone ; onglets sur ordinateur, sur toute la largeur.

Radio :

- [ ] Tous les tours annoncés, aucun manquant (*Telem Ratio* ≥ 1:16).
- [ ] Pose de ligne à l'arrêt (ligne armée, départ compté) et lancée.

### 11.2 Bancs matériels (à faire dans l'ordre)

| # | Banc | Critère | État |
|---|---|---|---|
| 1 | GNSS 25 Hz + écriture continue en flash 30 min | aucune trame GNSS perdue pendant les écritures | à faire |
| 2 | Trame GPS `0x02` vers la MT12 | capteur GPS découvert, coordonnées exactes | à faire |
| 3 | Trame `0x21` « L12 21.345 » | texte affiché sur la MT12 | ✅ |
| 4 | Script lisant `getValue("FM")` | chaîne lue telle quelle | ✅ |
| 5 | Lecture de CH8 (trame `0x16`) | seuils ±60 % franchis de façon fiable (inter et GV9) | à faire (mixage ✅) |
| 6 | Trames `0x0C` / `0x0D` | sans objet tant qu'aucune mesure moteur n'existe | — |
| 7 | Chrono firmware compilé sur PC | mêmes résultats que la console à 1 ms | ✅ (CI) |
| 8 | Wi-Fi actif près d'une radio ELRS 2,4 GHz | aucune baisse mesurable de LQ | à faire |

Bancs à la réception (`b` à chaque étape) : carte seule → + GPS dehors →
+ IMU → + récepteur → console (connexion, enregistrement, téléchargement,
effacement) → roulage (pose de ligne, tours radio, comparaison console).

---

## 12. Pièges connus — chapitre prioritaire

> Chacun de ces points vient d'une contrainte documentée de la plateforme ou
> d'un bug réellement rencontré. Un assistant qui repart de zéro les
> reproduira.

### 12.1 Longueur du nom Bluetooth

Nom du véhicule **≤ 16 caractères** : au-delà, la trame d'annonce déborde et le nom est
tronqué (et la console ne le trouve plus si le préfixe saute).

### 12.2 Réassemblage et longueur des écritures

- **Resynchronisation** (§8.3) : avancer de la longueur annoncée par une trame
  invalide fait sauter le début de la suivante. Symptôme : valeurs délirantes
  intermittentes (32,77 g = 32767, 7 670 544 km/h). Toujours avancer de 2.
- **Longueur des écritures** : la pile Bluetooth doit accepter les commandes
  de plus de 20 octets. NimBLE accepte 512 octets par défaut ; une pile qui
  plafonne à 20 rejette les écritures plus longues **sans aucun rappel** (les
  commandes disparaissent sans trace).

### 12.3 Ligne trop longue

Une ligne de 18 m recoupe le tracé à l'opposé d'un circuit RC : 10 traversées
pour 5 tours, temps faux. Remède : ligne courte (4 m de demi-longueur) **et**
proximité de l'ancrage **et** sens de passage.

### 12.4 Effacement non annulable

Journal en ajout linéaire : s'arrêter à mi-chemin laisserait des secteurs non
effacés devant le pointeur d'écriture. L'effacement va à son terme (il ne porte
que sur la zone utilisée, il est court). Il se fait **à rebours** (§4.3).

### 12.5 Tuiles satellite : l'erreur qui n'en est pas une

Au-delà de la couverture, Esri renvoie une tuile grise « Map data not yet
available » **avec un code HTTP 200**. Indétectable : plafonner à 19.

### 12.6 Ordre de déclaration en JavaScript

Une variable `let` lue avant sa déclaration lève « Cannot access 'X' before
initialization » (zone morte temporelle) : toute la page devient inerte.
Déclarer **toutes** les variables d'état en tête de script. Une vérification de
syntaxe ne le voit pas : **exécuter** la page (`tests/web`).

### 12.7 L'état décide, pas le clic

Réagir au *clic* sur un mode plutôt qu'à l'*état* du mode produit des
incohérences dès que l'ordre des actions change. Toujours recalculer depuis
l'état (même principe pour le mode circuit / dragster déduit des lignes posées).

### 12.8 Saturation de l'accéléromètre

À ±8 g, les trois axes plafonnent à 7,99 g aux atterrissages, avec des valeurs
qui semblent plausibles. Régler sur **±16 g** (`ACCEL_RANGE_G 16`). À surveiller
aux premiers roulages : des plateaux à 15,99 g imposeraient ±32 g (§12.17).

### 12.9 Le module ne pilote rien

Direction et ESC restent sur les sorties PWM du récepteur. Si le firmware
plante, la voiture reste pilotable. Aucune sortie de voie par le module, même
« pour simplifier le câblage ».

### 12.10 Émetteurs 2,4 GHz et radio de commande

Un Wi-Fi ou un Bluetooth actif à quelques centimètres d'un récepteur
ExpressLRS peut dégrader la liaison de commande : coupure **sans condition** au
roulage (§6.1). Un seul comportement, quel que soit le système radio.

### 12.11 Broches de l'ESP32-S3 N16R8

GPIO 35-37 (PSRAM octale) : les toucher fige ou redémarre la carte. GPIO 19-20 :
USB (plus de port de programmation). GPIO 0, 3, 45, 46 : lues au démarrage, un
niveau imposé peut empêcher le démarrage. ADC2 inutilisable Wi-Fi actif.

### 12.12 Boutisme CRSF

CRSF en **big-endian**, protocole TrimBox en **little-endian**, dans le même
firmware. Conversions par fonctions dédiées, jamais de `memcpy`. Symptôme : la
position GPS sur la radio à l'autre bout du monde, la console correcte.

### 12.13 Gel du cache pendant l'écriture en flash

§4.3. Symptôme d'un tampon trop petit : trames CRSF ou GNSS perdues de façon
intermittente, uniquement pendant un enregistrement, jamais au repos.

### 12.14 L'ESP32-S3 n'accepte pas le 5 V

Ses entrées ne sont **pas** tolérantes au 5 V. Un signal de niveau inconnu est
présumé à 5 V et passe par un pont diviseur. (Le TX du M100 Mini est à 3,3 V.)

### 12.15 La télémétrie radio sert à afficher, pas à calculer

Lente et avec pertes (quelques trames par seconde et par type). Les calculs se
font dans le module ; la radio n'affiche que des résultats.

### 12.16 Même algorithme, deux implémentations

Le chrono existe en JavaScript (console) et en C++ (firmware). Toute
modification de l'un **doit** être répercutée dans l'autre et validée par
`console_check.js`. Des résultats différents entre radio et console sur la même
session sont un bug.

### 12.17 Plage de l'accéléromètre et seuil de la console

Le seuil de plausibilité (20 g) est calibré pour ±16 g. Passer l'IMU à ±32 g
impose de le relever **en même temps** (35 g) : c'est la **seule** modification
admise dans `plausible()`, sur demande explicite. La plage réelle est transmise
par `FF F0` (champ `PLAGE_G`).

### 12.18 Alimentation de la DevKitC-1

Jamais le BEC (6 à 8,4 V) sur la broche 5V de la carte : régulateur 5 V en
amont obligatoire. Ne pas cumuler USB et régulateur sans vérifier le schéma
(retour de courant vers l'USB).

### 12.19 Émulateur QEMU : trois limites qui ne sont pas des bugs

La variante `-DTRIMBOX_QEMU` (jamais flashée sur la carte) contourne :

- flash en **QIO** : lectures décalées de 2 octets (mémoire « pleine »,
  configuration jamais relue) → **DIO** pour l'émulateur seulement ;
- **UART2 non émulé** : GNSS sur UART0 (partagé avec le journal, trames UBX
  extraites du flux texte), CRSF sur UART1 ;
- **RMT non émulé** : `rgbLedWrite()` attend indéfiniment → DEL désactivée.

Ni Bluetooth ni radio Wi-Fi dans l'émulateur : à valider sur la carte. Sans
`libslirp` sur la machine, QEMU ne démarre pas ; lancé avec `-nic none`, une
bibliothèque factice suffit.

### 12.20 GNSS allumé en permanence

Le GNSS est allumé dès le démarrage : chrono radio et pose de ligne doivent
fonctionner sans enregistrement. L'enregistrement, lui, repart toujours à
l'arrêt après une coupure (§4.5).

### 12.21 Fonctions appelées mais jamais définies

`refreshStatus()` / `refreshConfig()` étaient appelées mais définies nulle part
(console 1.7.1) : invisible en démo, état mémoire à zéro et téléchargement
refusé avec un vrai module. Même famille que §12.6 : seule l'exécution du vrai
parcours (`tests/web`) le révèle.

### 12.22 Pas de bibliothèque `table` dans les scripts de télémétrie EdgeTX

Constaté sur la MT12 : au premier tour reçu, « attempt to index a nil value
(field 'table') ». Le script se chargeait normalement : le plantage n'arrivait
qu'au premier message de chrono. `luac -p` ne voit rien. Garde-fou :
`tests/lua/test_trmbox.lua` et `tests/lua/radio_bridge.lua` posent `table = nil`
avant de charger le script. **À conserver.**

### 12.23 Les « optimisations » d'assistant

Trois corruptions de la console par un LLM local, présentées comme des
optimisations : `distM` réécrite en radians (distances divisées par ~57,
tracé invisible), `anal.pts` / `anal.scr` supprimés « pour libérer la mémoire »
(carte, tours et exports cassés), appel à `refreshTheme()` remplacé par un
commentaire « Optimisation » (textes des canevas invisibles en thème sombre).
D'où la liste des fonctions protégées (§8.13) et la validation par exécution.

### 12.24 Incrustations sur fond fixe, couleurs fixes

Une incrustation à fond sombre **fixe** (infobulle de la carte) qui utilise les
couleurs du thème (`var(--ink)`) devient illisible en thème clair (texte sombre
sur sombre). Les incrustations ont leurs propres couleurs (texte `#E6E1F2`,
valeurs blanches, étiquettes `#ADA5C8` : contraste ≥ 7:1), indépendantes du
thème et de l'accent.

### 12.25 Canevas à taille fixe étirés

Un canevas de 900 px de large affiché sur 340 ou 950 px avec une hauteur CSS
fixe déforme tracés et textes. La résolution interne suit la taille affichée
(§8.10) ; tout calcul de position souris passe par le rapport largeur interne /
largeur affichée, jamais par une largeur écrite en dur.

---

## 13. ESC XC-E8 (X-Bus) — piste close

**Conclusion du 22 septembre 2026 : la prise X-Bus du variateur ne fournit
aucune donnée.**

| Essai | Résultat |
|---|---|
| Analyseur logique, 4 MHz, 1,25 s | ligne **plate**, aucune transition |
| Sonde ESP32, test de tirage | la ligne remonte en 2 µs : résistance de tirage côté ESC, le fil est bien relié |
| Sonde ESP32, écoute passive 9 600 à 1 Mbaud | rien |
| Poignée de main SRXL2, 11 adresses, 115 200 et 400 000 bauds | aucune réponse |
| Application : *PLine* | X.BUS, Max.Brake, Max.Rev, Acc, DragBrake — que des **entrées** |
| Application : *ProtocolId* | 0 à 15 : un numéro d'appareil sur le bus |

Conséquences : régime, tension, courant et températures **inaccessibles** par
cette prise ; la tension de batterie vient du récepteur ; GPIO 5 et 6 libres ;
type `0x28` et message `FF 28` réservés. Pistes en réserve si le besoin
revient : régime par un fil Hall de la nappe de capteurs du moteur (4 fronts par
tour avec 2 paires de pôles), température par sa thermistance, tension par pont
diviseur sur l'ADC1. Outil conservé : `tools/xbus_probe/`.

---

## Annexe A — Correspondance des anciens renvois

Les anciens documents numérotaient « v1 §x » (carte XIAO) et « v2 §y ». Les
renvois du code ont été convertis ; cette table sert pour les historiques.

| Ancien | Nouveau | | Ancien | Nouveau |
|---|---|---|---|---|
| v1 §1 | §1 | | v2 §0 | §0 |
| v1 §3, §3.x | §3, §3.x | | v2 §2.x | §2.x |
| v1 §4.1 | §4.1 | | v2 §3.2 | §4.1 |
| v1 §4.2 | §4.2 | | v2 §3.3 | §4.3 |
| v1 §4.3 | §2.4, §3.11 | | v2 §3.4 | §4.4 |
| v1 §4.4 | §4.4 | | v2 §4, §4.1-4.3 | §5, §5.1-5.3 |
| v1 §4.5 | §4.5 | | v2 §4.4 | §5.4 |
| v1 §4.6 | §4.6 | | v2 §4.5 | §5.5 |
| v1 §4.7 | §4.7 | | v2 §4.6 | §5.6 |
| v1 §4.8 | §4.8 | | v2 §5 | §13 |
| v1 §4.9 | §4.12 | | v2 §6, §6.3 | §3, §3.4 |
| v1 §5.2 | §8.3 | | v2 §6.1 | §3.2 |
| v1 §5.3 | §8.4 | | v2 §6.2 | §3.11 |
| v1 §5.4 | §8.5, §8.6 | | v2 §6.4 | §8.7 |
| v1 §5.5 à §5.10 | §8.8 à §8.12 | | v2 §7, §7.1 | §6, §6.1 |
| v1 §6 | §10.1 | | v2 §7.2 | §7 |
| v1 §8 | §11 | | v2 §7.3 | §6.4 |
| v1 §8.3 | §10.2 | | v2 §8 | §9 |
| v1 §9 | §12 | | v2 §9 | §11.2 |
| v1 §9.4 | §12.1 | | v2 §9.1 | §10.1 |
| v1 §9.5, §9.5a, §9.5b | §12.2 | | v2 §10 | §12 |
| v1 §9.6 | §12.3 | | v2 §10.1 à §10.14 | §12.9 à §12.22 |
| v1 §9.7 | §12.4 | | | |
| v1 §9.8 | §12.5 | | | |
| v1 §9.9 | §12.6 | | | |
| v1 §9.10 | §12.7 | | | |
| v1 §9.11 | §12.8 | | | |

Supprimés (propres à la carte XIAO) : variante mbed, conflit de type `File`,
`adafruit-nrfutil`, erreur de copie UF2, flash QSPI P25Q16H, compilation
Seeeduino / PlatformIO.

## Annexe B — Points ouverts

| Point | Bloquant pour | Résolution |
|---|---|---|
| Révision de la DevKitC-1 (DEL sur GPIO 48 ou 38) | §4.11 | Sérigraphie de la carte |
| Plage accéléromètre suffisante à ±16 g | §2.5, §12.17 | Premiers roulages : plateaux à 15,99 g ? |
| `IMU_AVERAGE` 1 ou 0 | §4.9 | Même roulage analysé dans les deux modes |
| Repli GPS seul si Galileo empêche les 25 Hz | §4.8 | Mesure dehors (`b`) |
| Pose de ligne à l'arrêt, enregistrement automatique | §5.5, §4.6 | Roulage |
| Bluetooth coupé au roulage | §6.3 | `b` en roulant |
| Bancs 1, 2, 5, 8 | §11.2 | Matériel |
| `FF 29` en direct | §3.4 | Le firmware ne l'émet qu'au téléchargement ; la console sait déjà le journaliser |
| Nettoyage console : commentaires « Optimisation » orphelins, `addSession()` / `MAX_SESSIONS` jamais appelés, contraste du texte « démonstration » en thème clair, durées absentes de la liste des cadences en démo | §8 | Développement console |

## Annexe C — Glossaire

| Terme | Définition |
|---|---|
| **Fix** | Verrouillage du récepteur GNSS. Type 3 = position 3D valide |
| **iTOW** | *Time of Week*, horodatage GNSS en millisecondes |
| **CRSF** | Protocole série Crossfire, repris par ExpressLRS, entre récepteur et contrôleur |
| **ELRS** | ExpressLRS, système radio 2,4 GHz |
| **FM** | Capteur « mode de vol » d'EdgeTX, alimenté par la trame CRSF `0x21` |
| **GV9** | Variable globale n° 9 du modèle EdgeTX |
| **OTA** | *Over The Air* : mise à jour du firmware sans câble |
| **MTU** | Taille maximale d'un paquet Bluetooth négociée à la connexion |
| **NUS** | *Nordic UART Service*, service Bluetooth série |
| **Portail captif** | Mécanisme qui fait ouvrir une page au téléphone à la connexion Wi-Fi |
| **VBO** | Format de télémétrie Racelogic (RaceChrono, Circuit Tools) |
| **Tuile** | Image carrée de 256 px composant un fond cartographique |

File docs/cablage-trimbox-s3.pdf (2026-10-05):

# TrimBox — schéma de câblage

ESP32-S3-DevKitC-1 (N16R8) · GPS HGLRC M100 Mini · IMU LSM6DS3 · récepteur RadioMaster ER5C-i (ExpressLRS) · ESC XC-E8 Firmware 2.0-a14 — brochage défini dans trimbox_s3/src/config.h

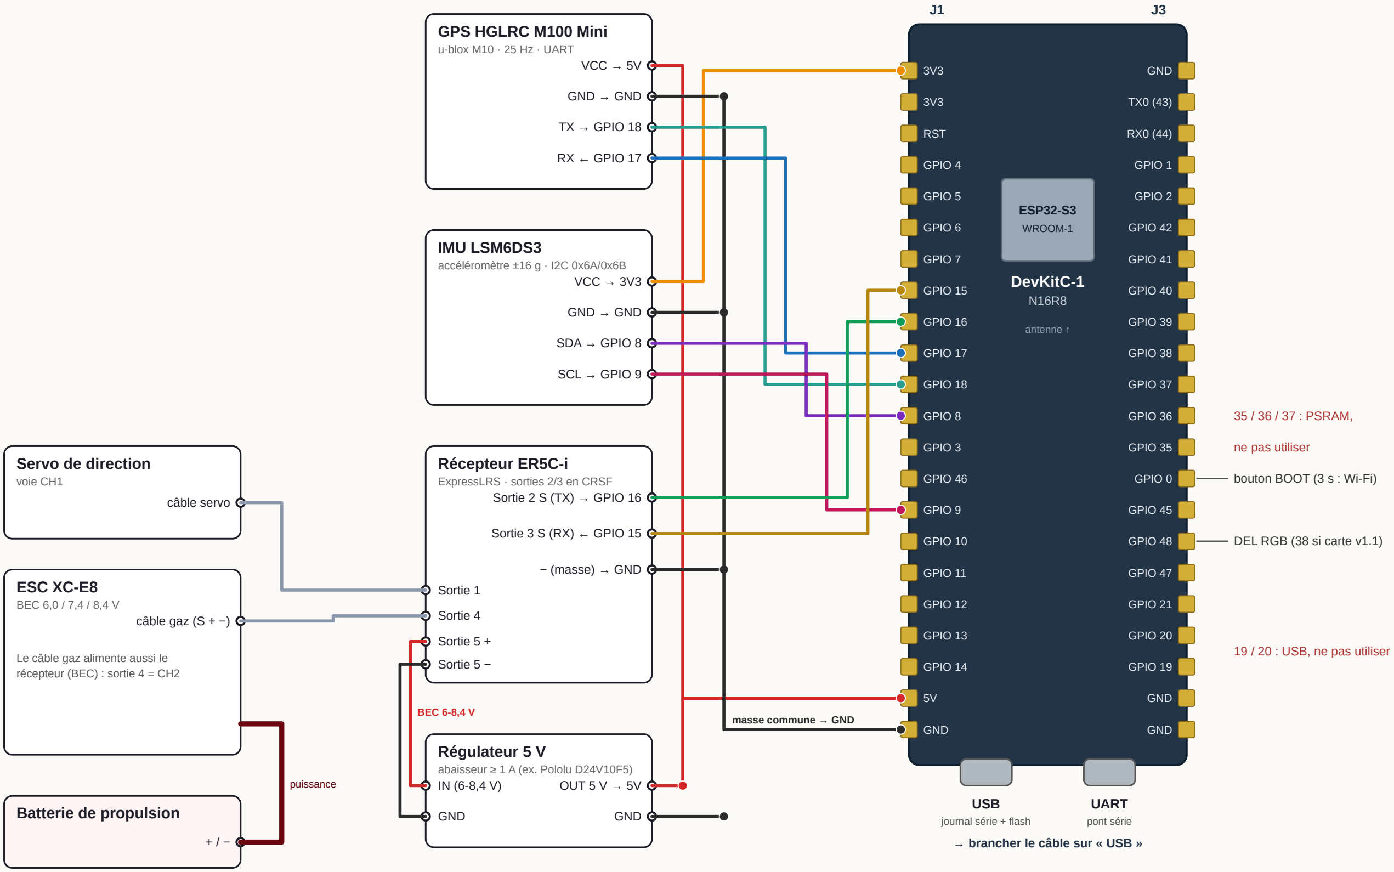
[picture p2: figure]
ESP32-S3; WROOM-1; DevKitC-1; antenne ↑; RST; GPIO 4; GPIO 5; GPIO 6; GPIO 7; GPIO 15; GPIO 16; GPIO 17; GPIO 18; GPIO 8; GPIO 3; GPIO 46; GPIO 9; GPIO 10; GPIO 11; GPIO 12; GPIO 13; GPIO 14; GND; GPIO 1; GPIO 2; GPIO 42; GPIO 41; GPIO 40; GPIO 39; GPIO 38; GPIO 37; GPIO 36; GPIO 35; GPIO 0; GPIO 45; GPIO 48; GPIO 47; GPIO 21; GPIO 20; GPIO 19; bouton BOOT (3 s : Wi-Fi); DEL RGB (38 si carte v1.1); 19 / 20 : USB, ne pas utiliser; 35 / 36 / 37 : PSRAM,; ne pas utiliser; USB; journal série + flash; UART; pont série; → brancher le câble sur « USB »; GPS HGLRC M100 Mini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

### Légende

5 V
3,3 V
Masse (GND)
GPS UART (TX / RX)
IMU I2C (SDA / SCL)
CRSF récepteur (TX / RX)
Voies PWM du récepteur
- = connexion · croisement sans point = pas de contact

### À respecter

Jamais plus de 3,3 V sur une broche GPIO.
TX et RX CROISÉS : TX du module → RX de la carte. BEC (6 à 8,4 V) : jamais directement sur « 5V », toujours via le régulateur 5 V.
Au banc : l'USB alimente tout — régulateur
débranché (ne pas cumuler USB + régulateur). Masse commune entre tous les éléments. ER5C-i (page web, onglet Model) : sorties 2 et 3 en Serial TX / RX, protocole CRSF ; direction sur la sortie 1 (CH1) ; ESC sur la sortie 4 (CH2). Sorties du récepteur : ordre physique et fils
selon la sérigraphie ; couleurs du GPS à vérifier. IMU vissée rigidement, axes alignés sur la voiture.

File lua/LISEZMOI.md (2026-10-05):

# Script Lua TrimBox pour RadioMaster MT12

`trmbox.lua` : écran de télémétrie EdgeTX (128 × 64) qui affiche le chrono
calculé par le module, annonce chaque tour et pose les lignes de départ et
d'arrivée **depuis la radio**.

## Installation

1. Brancher la MT12 en USB, choisir *Stockage USB (carte SD)*.
2. Copier `trmbox.lua` dans **`SCRIPTS/TELEMETRY/`** (le nom doit rester de
   6 caractères au plus : limite d'EdgeTX pour ces écrans).
3. **Voix** : copier le dossier **`lua/SOUNDS`** du dépôt à la racine de la
   carte SD (il se fusionne avec le `SOUNDS` existant : seul
   `SOUNDS/trimbox/` est ajouté). Les 12 mots y sont déjà, générés avec la voix
   du pack français d'EdgeTX (WAV 16 bits, mono, 16 kHz). Sans eux, le script
   remplace chaque mot par un bip.
4. Sur la radio : *Radio → Général → Langue des voix* = **Français**.
5. Sur la radio : **Modèle → Télémétrie → Découvrir les capteurs**, voiture
   et module allumés. Doivent apparaître notamment `GPS`, `GSpd`, `Sats`,
   `RQly` et **`FM`** (messages du chrono).
6. Toujours dans *Télémétrie*, **Écran 1 → Script → trmbox**.
7. Affichage : depuis l'écran principal, **appui long sur TELE** (ou la touche
   de pages de télémétrie selon la version d'EdgeTX).

## Mixage de la voie 8 (pose de ligne) — INDISPENSABLE

Le script n'envoie rien au module directement : il écrit la variable globale
**GV9**, et c'est un **mixage** qui la transmet sur **CH8**, la voie que le
module écoute. **Sans ce mixage, les commandes de pose ne partent pas** : la
page *Lignes* affiche `Mode : aucune`, et rien ne se passe à l'appui.

Sur la MT12, *Modèle → Mixeur*, ligne **CH8** :

1. Sélectionner **CH8** et l'ouvrir (appui long → *Modifier*, ou *Insérer*
   si la ligne est vide).
2. **Source** : `MAX`.
3. **Poids** : appuyer sur la valeur et la remplacer par la variable
   globale **GV9** (tourner la molette au-delà de 100 : les GV apparaissent
   après les nombres, ou appui long sur le champ selon la version).
4. **Mode / opération** : `+=` (« Ajouter »).
5. Sortir. Au repos, CH8 doit afficher **0 %** (page *Sorties* ou l'écran des
   voies) : le module ignore toute commande tant qu'il n'a pas vu la voie au
   neutre.

**Vérification immédiate** : la page *Lignes* du script affiche en bas à
gauche la valeur réelle de la voie, `CH8 +0%`. Pendant un envoi, elle doit
passer à **+100 %** (départ) ou **−100 %** (arrivée, effacement). Si elle
reste à 0, le script prévient : « **CH8 immobile : mixage ?** ».

Autre possibilité, sans le script : un **inter 3 positions** (SA par exemple)
directement sur CH8, poids 100, mode Ajouter. Haut 0,5 s = départ ; bas 0,5 à
3 s = arrivée ; bas 3 s = effacement.

## Annonces vocales

À chaque passage de ligne :

1. « **meilleur tour** » si c'est ton record de la session ;
2. **le temps du tour**, au centième : « vingt et un virgule trente-quatre » ;
3. **l'écart avec le tour précédent** : « moins zéro virgule trente-cinq »
   (plus rapide), « plus un virgule zéro zéro » (plus lent), ou « égal »
   (moins d'un demi-centième d'écart).

L'écart n'est annoncé que si le tour précédent a bien été reçu (numéros qui
se suivent) : après une coupure radio, pas de comparaison trompeuse.

À la pose d'une ligne, la radio confirme : « départ posé », « arrivée
posée », « lignes effacées », ou refuse : « vitesse trop faible », « pas de
GPS », « commande refusée ».

**Les nombres** sont dits par le pack vocal de la radio (`SOUNDS/fr/`).
**Les mots** sont 12 fichiers de `SOUNDS/trimbox/`, fournis dans le dépôt
(`lua/SOUNDS/trimbox/`). Pour les refaire, avec l'outil de synthèse vocale de
ton choix :

| Fichier | Texte |
|---|---|
| `meilleur.wav` | meilleur tour |
| `plus.wav` / `moins.wav` / `egal.wav` | plus / moins / égal |
| `depart.wav` / `arrivee.wav` / `efface.wav` | départ posé / arrivée posée / lignes effacées |
| `arme.wav` / `delai.wav` | ligne armée, roulez / délai dépassé |
| `vitfaib.wav` / `pasgps.wav` / `refus.wav` | vitesse trop faible / pas de GPS / commande refusée |
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

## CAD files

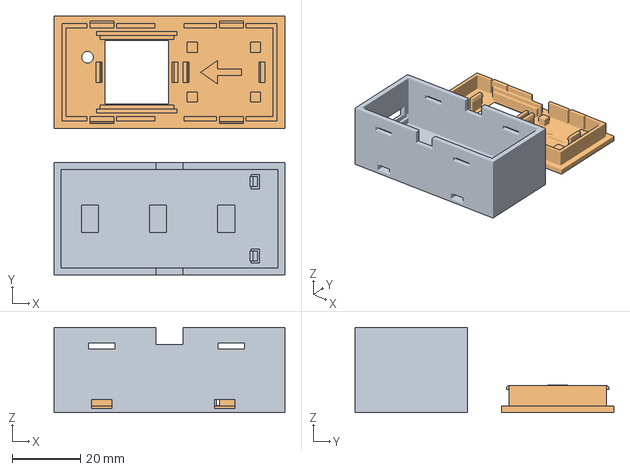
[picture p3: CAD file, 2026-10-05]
docs/boitier/trimbox-boitier.3mf
67.7 x 76.0 x 25.0 mm
TrimBox fond
TrimBox couvercle (retourne)

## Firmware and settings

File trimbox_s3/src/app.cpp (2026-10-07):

// ============================================================================
//  TrimBox — application
//
//  Boucle principale NON BLOQUANTE, dans cet ordre strict (§4.1) : le
//  protocole passe avant tout le reste, pour qu'aucune commande ne reste
//  sans réponse.
//    1. commandes de secours (port série USB)
//    2. commandes de la console (Bluetooth) → réponses dans la file unique
//    3. effacement progressif (un secteur par tour)
//    4. téléchargement progressif (tant que la file a de la place)
//    5. vidange de la file vers le Bluetooth
//    6. extinction automatique
//    7. acquisition : IMU, GNSS, radio, enregistrement, chronométrage
// ============================================================================
#include "app.h"
#include "config.h"
#include "core/tbproto.h"
#include "core/records.h"
#include "core/recorder.h"
#include "core/stillhold.h"
#include "core/linearm.h"
#include "core/airgate.h"
#include "core/lapcore.h"
#include "core/linecmd.h"
#include "core/persist.h"
#include "core/bytes.h"
#include "hw/storage.h"
#include "hw/gnss.h"
#include "hw/imu.h"
#include "hw/bridge.h"
#include "hw/radio.h"
#include "hw/wifiap.h"
#include "hw/ota.h"
#include "hw/identity.h"
#include "core/ident.h"
#include <Arduino.h>
#include <esp_sleep.h>
#include <esp_mac.h>
#include <math.h>

namespace app {

// ---------------------------------------------------------------------------
//  État — tout est déclaré ici, en tête (leçon de §12.6, valable aussi en C++
//  pour la lisibilité : aucune variable d'état dispersée dans le fichier).
// ---------------------------------------------------------------------------
static persist::RecConfig  g_cfg;
static persist::LineConfig g_lines;
static recd::Recorder      g_rec;
static still::Hold         g_still;     // position figée à l'arrêt
static lap::Engine         g_lap;
// Pose « à l'arrêt, puis on démarre » : ligne armée, et points mémorisés
// depuis l'armement pour rejouer le départ dans le chrono une fois la ligne
// posée (le franchissement a eu lieu AVANT que le cap soit connu).
static linearm::Armer      g_arm;
static constexpr uint16_t  ARM_BUF = 600;               // 24 s à 25 Hz
static lap::Point          g_armBuf[ARM_BUF];
static uint16_t            g_armN = 0, g_armHead = 0;
static tb::Parser          g_rx(true);
static bool     g_storageOk = false, g_imuOk = false, g_gnssOk = false;
static char     g_serial[20];

static struct {                 // téléchargement en cours
  bool active; bool extended; uint32_t idx, end, sent, rejected;
} g_dl = {};
static uint8_t  g_erasePct = 255;

static rec::Pvt g_pvt = {};     // dernière solution
static bool     g_havePvt = false;
static uint32_t g_itowPrev = 0; static double g_weekOffset = 0;   // iTOW continu

// Historique court des solutions, horodaté à l'arrivée, pour situer la
// voiture à l'instant exact d'un geste sur l'inter (pose de ligne).
struct Hist { uint32_t ms; int32_t lat, lon, head, gSpeed; bool fix; };
static Hist     g_hist[64]; static uint8_t g_histN = 0, g_histHead = 0;

static int32_t  g_prevBestMs = 0;     // pour l'écart au meilleur tour

// Point d'accès Wi-Fi automatique (§6.1)
static tb::Parser g_rxWs(true);       // commandes reçues par WebSocket
static bool     g_wifiAuto = WIFI_AUTO_DEFAULT;
static bool     g_moving = false;     // la voiture roule (confirmé)
static bool     g_stillEpoch = true;  // dernière solution : « à l'arrêt »
static uint32_t g_lastPvtMs = 0;
// Roule / à l'arrêt, et décision d'allumer ou de couper les radios de la
// console (core/airgate, testé sur PC).
static airgate::Motion g_motion;
static airgate::Gate   g_wifiGate(WIFI_AUTO_ON_S * 1000u);
static airgate::Gate   g_bleGate(BLE_AUTO_ON_S * 1000u);
static uint32_t g_btnDown = 0; static bool g_btnFired = false;
static char     g_ssid[33];
// Identité (nom du véhicule, mot de passe Wi-Fi), lue en NVS au démarrage.
// Un changement par FF F3 est enregistré puis le module redémarre : le
// point d'accès et le Bluetooth repartent sous le nouveau nom.
static identity::Ident g_id;
static char     g_bleName[32];
static uint32_t g_restartAt = 0;          // millis() du redémarrage demandé (0 : aucun)
static uint32_t g_bootMs = 0, g_lastLed = 0;

// ---------------------------------------------------------------------------
//  Outils
// ---------------------------------------------------------------------------
static void ack(uint8_t id){ uint8_t p[2] = {tb::CLS, id}; bridge::send(tb::CLS, tb::ID_ACK, p, 2); }
static void nack(uint8_t id){ uint8_t p[2] = {tb::CLS, id}; bridge::send(tb::CLS, tb::ID_NACK, p, 2); }

// Temps en millisecondes → "21.345" (entiers uniquement, §5.4).
static void fmtMs(char* out, size_t cap, int32_t ms, bool sign){
  const char* s = ms < 0 ? "-" : (sign ? "+" : "");
  const uint32_t a = (uint32_t)(ms < 0 ? -ms : ms);
  snprintf(out, cap, "%s%lu.%03lu", s, (unsigned long)(a / 1000), (unsigned long)(a % 1000));
}

static void configPayload(uint8_t p[12]){
  p[0] = g_cfg.enabled; p[1] = g_cfg.dataRate; p[2] = g_cfg.flags; p[3] = 0;
  put_le16(p+4, g_cfg.statSpeed); put_le16(p+6, g_cfg.statInterval);
  put_le16(p+8, g_cfg.noFixInterval); put_le16(p+10, g_cfg.autoOffInterval);
}

static void applyRecorderSettings(){
  recd::Settings s;
  s.flags = g_cfg.flags; s.statSpeed = g_cfg.statSpeed; s.statInterval = g_cfg.statInterval;
  s.noFixInterval = g_cfg.noFixInterval; s.autoOffInterval = g_cfg.autoOffInterval;
  g_rec.configure(s);
}

// Texte d'état envoyé à la radio : « S REC C » = enregistre, lignes en
// circuit (C), dragster (D) ou aucune (-). Le script Lua en tire l'état des
// lignes, conservées par le module d'un démarrage à l'autre.
static const char* stateText(){
  static char t[16];
  const char* st;
  switch(g_rec.state()){
    case recd::RECORDING: st = (g_havePvt && g_pvt.fixType >= 3) ? "REC" : "NOFIX"; break;
    case recd::PAUSED:    st = "PAUSE"; break;
    default:              st = "STOP"; break;
  }
  snprintf(t, sizeof t, "S %s %c", st, g_lines.mode == 2 ? 'D' : g_lines.mode == 1 ? 'C' : '-');
  return t;
}

// Changement d'état : notifié à la console, stocké si demandé.
static void stateChanged(uint8_t reason, bool store){
  uint8_t p[12];
  rec::buildState(p, g_rec.state(), reason, g_havePvt ? g_pvt.iTOW : 0, g_rec.pointsStored());
  bridge::send(tb::CLS, tb::ID_STATE, p, 12);
  if(store && g_storageOk){
    uint8_t slot[80] = {0}; memcpy(slot, p, 12);
    storage::append(rec::SLOT_STATE, slot);
  }
  radio::status(stateText());
  Serial.printf("[rec] état %u (motif %u)%s\n", g_rec.state(), reason, store ? ", stocké" : "");
  // Frontière de session : le chrono repart de zéro, comme la console qui
  // découpe les sessions aux changements d'état stockés.
  if(store){ g_lap.flush(); g_lap.reset(); }
}

static void startRecording(uint8_t reason){
  if(g_rec.start(millis())) stateChanged(reason, true);
}
static void stopRecording(uint8_t reason){
  if(g_rec.stop()) stateChanged(reason, true);
}

static void saveCfg(){ if(g_storageOk && !storage::saveRecConfig(g_cfg)) Serial.println("[cfg] ÉCHEC d'écriture"); }

// ---------------------------------------------------------------------------
//  Lignes
// ---------------------------------------------------------------------------
static bool startSet(){  return g_lines.startLat  != 0 || g_lines.startLon  != 0; }
static bool finishSet(){ return g_lines.finishLat != 0 || g_lines.finishLon != 0; }

static void applyLines(){
  g_lines.mode = startSet() && finishSet() ? 2 : (startSet() || finishSet()) ? 1 : 0;
  lap::Line A, B;
  if(startSet())  A = lap::makeLineFromHeading(g_lines.startLat / 1e7,  g_lines.startLon / 1e7,  g_lines.startHeading / 1e5);
  if(finishSet()) B = lap::makeLineFromHeading(g_lines.finishLat / 1e7, g_lines.finishLon / 1e7, g_lines.finishHeading / 1e5);
  // Circuit avec seule l'arrivée posée : la console utilise « B || A » ;
  // le moteur, lui, prend la ligne A quand B est seule.
  if(!A.set && B.set){ A = B; B = lap::Line(); }
  g_lap.setLines(A, B);
  g_prevBestMs = 0;
}

static bool positionAt(uint32_t atMs, int32_t& lat, int32_t& lon, int32_t& head, int32_t& speed){
  if(g_histN < 2) return false;
  for(uint8_t k = 0; k + 1 < g_histN; k++){
    const Hist& a = g_hist[(g_histHead + 64 - g_histN + k) % 64];
    const Hist& b = g_hist[(g_histHead + 64 - g_histN + k + 1) % 64];
    if(atMs < a.ms || atMs > b.ms) continue;
    if(!a.fix || !b.fix) return false;
    const double f = b.ms > a.ms ? (double)(atMs - a.ms) / (b.ms - a.ms) : 0;
    lat = (int32_t)llround(a.lat + (b.lat - a.lat) * f);
    lon = (int32_t)llround(a.lon + (b.lon - a.lon) * f);
    head = b.head; speed = b.gSpeed < a.gSpeed ? b.gSpeed : a.gSpeed;
    return true;
  }
  // Geste plus récent que la dernière solution reçue : on prend celle-ci.
  const Hist& last = g_hist[(g_histHead + 63) % 64];
  if(atMs >= last.ms && atMs - last.ms < 200 && last.fix){
    lat = last.lat; lon = last.lon; head = last.head; speed = last.gSpeed; return true;
  }
  return false;
}

static void onLineCommand(const linecmd::Output& o){
  if(o.cmd == linecmd::Cmd::Clear){
    g_lines.startLat = g_lines.startLon = g_lines.startHeading = 0;
    g_lines.finishLat = g_lines.finishLon = g_lines.finishHeading = 0;
    applyLines();
    if(g_storageOk) storage::saveLineConfig(g_lines);
    radio::event("K EFFACE");
    Serial.println("[ligne] lignes effacées");
    return;
  }
  int32_t lat, lon, head, speed;
  if(!positionAt(o.atMs, lat, lon, head, speed)){ radio::event("K PAS DE FIX"); return; }
  const bool start = o.cmd == linecmd::Cmd::PoseStart;
  if(speed < LINE_MIN_SPEED_MMS){
    // Voiture (quasi) arrêtée SUR la ligne : on arme, le cap sera celui du
    // départ. Il faut démarrer dans les 10 s.
    g_arm.arm(start ? linearm::Which::Start : linearm::Which::Finish, lat, lon, millis());
    g_armN = g_armHead = 0;
    radio::event(start ? "K ARME DEPART" : "K ARME ARRIVEE");
    Serial.printf("[ligne] %s armée en %.7f %.7f : démarrer dans les %lu s\n", start ? "départ" : "arrivée",
                  lat / 1e7, lon / 1e7, (unsigned long)(LINE_ARM_WINDOW_MS / 1000));
    return;
  }
  g_arm.cancel();
  if(start){ g_lines.startLat = lat; g_lines.startLon = lon; g_lines.startHeading = head; }
  else     { g_lines.finishLat = lat; g_lines.finishLon = lon; g_lines.finishHeading = head; }
  applyLines();
  if(g_storageOk) storage::saveLineConfig(g_lines);
  radio::event(start ? "K DEPART OK" : "K ARRIVEE OK");
  Serial.printf("[ligne] %s posée : %.7f %.7f cap %.1f°\n", start ? "départ" : "arrivée", lat / 1e7, lon / 1e7, head / 1e5);
}

// ---------------------------------------------------------------------------
//  Événements du chronométrage
// ---------------------------------------------------------------------------
static void storeLapSlot(const lap::Event& e){
  if(!g_storageOk || g_rec.state() != recd::RECORDING) return;
  uint8_t s[80] = {0};
  // [0] u32 iTOW (ms)  [4] u8 ligne  [5] u8 nature (0 passage, 1 tour,
  // 2 parcours, 3 chrono intermédiaire)  [6] u16 n°  [8] u32 temps (ms)
  // [12] u8 type de chrono (0 vitesse, 1 distance)  [14] u16 valeur
  const uint32_t itow = e.kind == lap::EventKind::Crossing
                      ? (uint32_t)fmod(llround(e.t * 1000.0), 604800000.0) : (g_havePvt ? g_pvt.iTOW : 0);
  put_le32(s, itow); s[4] = e.line; s[5] = (uint8_t)e.kind; put_le16(s+6, e.n);
  if(e.kind != lap::EventKind::Crossing) put_le32(s+8, (uint32_t)llround(e.t * 1000.0));
  s[12] = e.splitKind; put_le16(s+14, (uint16_t)e.splitValue);
  storage::append(rec::SLOT_LAP, s);
}

static void onLapEvent(const lap::Event& e, void*){
  storeLapSlot(e);
  char txt[40], a[16], b[16];
  const int32_t ms = (int32_t)llround(e.t * 1000.0);
  switch(e.kind){
    case lap::EventKind::Lap:
    case lap::EventKind::Run: {
      // UN seul message par tour (ExpressLRS n'en transmet qu'un à la fois) :
      // « L12 21.345+0.35 » = tour 12, 21,345 s, 0,35 s de plus que le
      // meilleur tour précédent (négatif : nouveau meilleur tour).
      // L'écart est omis au premier tour, ou si le texte dépasserait 15
      // caractères. Le script Lua déduit lui-même le meilleur tour.
      fmtMs(a, sizeof a, ms, false);
      snprintf(txt, sizeof txt, "L%u %s", e.n, a);
      if(e.n > 1){
        const int32_t dcs = (int32_t)lround((ms - g_prevBestMs) / 10.0);   // centièmes
        const uint32_t ad = (uint32_t)(dcs < 0 ? -dcs : dcs);
        snprintf(b, sizeof b, "%c%lu.%02lu", dcs < 0 ? '-' : '+', (unsigned long)(ad / 100), (unsigned long)(ad % 100));
        if(strlen(txt) + strlen(b) <= 15) strcat(txt, b);
      }
      radio::event(txt);
      g_prevBestMs = (int32_t)llround(e.best * 1000.0);
      Serial.printf("[chrono] %s %u : %s\n", e.kind == lap::EventKind::Lap ? "tour" : "parcours", e.n, a);
      break;
    }
    case lap::EventKind::Split:
      fmtMs(a, sizeof a, ms, false);
      if(e.splitKind == 0) snprintf(txt, sizeof txt, "R 0-%u %s", (unsigned)e.splitValue, a);
      else                 snprintf(txt, sizeof txt, "R %um %s", (unsigned)e.splitValue, a);
      radio::event(txt);
      break;
    default: break;
  }
}

// ---------------------------------------------------------------------------
//  Point d'accès Wi-Fi
// ---------------------------------------------------------------------------
static void wifiSet(bool want, const char* why){
  if(want == wifiap::on()) return;
  if(want){
    if(wifiap::start()){ radio::event("W WIFI ON"); Serial.printf("[wifi] allumé (%s)\n", why); }
  }else{
    wifiap::stop(); radio::event("W WIFI OFF"); Serial.printf("[wifi] éteint (%s)\n", why);
  }
}

// Wi-Fi ET Bluetooth : coupure IMMÉDIATE dès que la voiture roule (3
// solutions GNSS de suite au-dessus de 7,2 km/h), quel que soit le mode : la
// radio de commande passe avant la console. Rallumage après WIFI_AUTO_ON_S
// (BLE_AUTO_ON_S) secondes d'arrêt continu (sous 5 km/h, ou sans fix).
static void serviceRadios(uint32_t now){
  const bool stale = !g_havePvt || now - g_lastPvtMs > 2000;   // pas de GNSS : réputé à l'arrêt
  switch(g_wifiGate.step(now, stale, g_moving, g_stillEpoch, wifiap::on(), g_wifiAuto)){
    case airgate::Act::Off: wifiSet(false, "la voiture roule"); break;
    case airgate::Act::On:  wifiSet(true, "arrêt prolongé"); break;
    default: break;
  }
#if BLE_AUTO_OFF && !defined(TRIMBOX_QEMU)
  switch(g_bleGate.step(now, stale, g_moving, g_stillEpoch, bridge::bleEnabled(), true)){
    case airgate::Act::Off: bridge::bleEnable(false); Serial.println("[ble] coupé (la voiture roule)"); break;
    case airgate::Act::On:  bridge::bleEnable(true);  Serial.println("[ble] rallumé (arrêt prolongé)"); break;
    default: break;
  }
#endif
}

// Appui long sur BOOT : bascule marche / arrêt du Wi-Fi.
static void serviceButton(uint32_t now){
  const bool down = digitalRead(PIN_BUTTON) == LOW;
  if(!down){ g_btnDown = 0; g_btnFired = false; return; }
  if(!g_btnDown) g_btnDown = now ? now : 1;
  if(!g_btnFired && now - g_btnDown >= BUTTON_LONG_MS){
    g_btnFired = true;
    if(wifiap::on()){ g_wifiAuto = false; wifiSet(false, "bouton"); }
    else if(!g_moving){ g_wifiAuto = true; wifiSet(true, "bouton"); }
  }
}

// ---------------------------------------------------------------------------
//  Mise à jour par Wi-Fi : conditions (§7)
// ---------------------------------------------------------------------------
static const char* otaGate(){
  if(g_rec.state() != recd::STOPPED) return "arrêtez d'abord l'enregistrement";
  if(g_moving) return "la voiture roule";
  if(g_dl.active) return "un téléchargement est en cours";
  if(storage::erasing()) return "un effacement est en cours";
  return nullptr;
}
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
void loop(){
  // Redémarrage demandé (nouvelle identité) : après l'envoi de l'accusé.
  if(g_restartAt && (int32_t)(millis() - g_restartAt) >= 0){
    Serial.println("[id] redémarrage"); Serial.flush();
    ESP.restart();
  }
#ifndef TRIMBOX_QEMU
  serviceSerialCommands();                             // 1
#else
  // Émulateur : UART0 est partagé avec le faux GNSS, pas de commandes.
  static uint32_t lastInfo = 0;
  if(millis() - lastInfo > 10000){ lastInfo = millis(); printInfo(); printBench(); }
#endif
  uint8_t buf[128]; size_t n;                          // 2
  while((n = bridge::read(buf, sizeof buf)) > 0) g_rx.push(buf, n);
  wifiap::service();
  while((n = wifiap::read(buf, sizeof buf)) > 0) g_rxWs.push(buf, n);
  tb::Frame f;
  while(g_rx.next(f)) onCommand(f);
  while(g_rxWs.next(f)) onCommand(f);
  serviceErase();                                      // 3
  serviceDownload();                                   // 4
  bridge::service();                                     // 5
  // 6 : l'extinction est décidée par l'automate, à chaque époque (onPvt)
  imu::poll();                                         // 7
  rec::Pvt p;
  if(g_gnssOk && gnss::poll(p)) onPvt(p);
  const linecmd::Output o = radio::poll();
  if(o.cmd != linecmd::Cmd::None) onLineCommand(o);
  const uint32_t now = millis();
  serviceRadios(now);
  {
    static bool wasPending = ota::pendingValidation(), wasReboot = false;
    ota::serviceValidation(g_storageOk);
    if(wasPending && !ota::pendingValidation()){ wasPending = false; radio::event("U MAJ OK"); }
    if(!wasReboot && ota::rebootPending()){ wasReboot = true; radio::event("U REDEMARRAGE"); }
  }
#ifndef TRIMBOX_QEMU      // GPIO 0 non câblé dans l'émulateur
  serviceButton(now);
#endif
  serviceLed();
}

} // namespace app

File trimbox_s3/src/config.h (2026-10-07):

// ============================================================================
//  TrimBox — configuration de compilation
//  Cahier des charges. Les valeurs numériques ne sont PAS indicatives
//  (v1, « Comment utiliser ce document ») : ne pas les changer sans raison.
// ============================================================================
#pragma once

// ---------------------------------------------------------------- identité
#define DEVICE_NICKNAME   "Buggy 1"          // nom du véhicule PAR DÉFAUT, ≤ 16 caractères (§12.1) ;
                                             // modifiable depuis la console (Réglages), gardé en NVS
#define BRAND             "TrimBox"
#define FIRMWARE_VER      "2.0-a16"
#define HARDWARE_VER      "ESP32-S3-DevKitC-1 N16R8"
#define MANUFACTURER      "TrimBox"
#define BUILD_STAMP       __DATE__ " " __TIME__

// ---------------------------------------------------------------- brochage
// §2.3. INTERDITES : 35-37 (PSRAM octale), 19-20 (USB), 0/3/45/46 en
// sortie (configuration au démarrage). ADC : uniquement l'ADC1 (GPIO 1-10).
#define PIN_GNSS_RX       18    // ← TX du module GNSS
#define PIN_GNSS_TX       17    // → RX du module GNSS
#define PIN_GPS_EN        10    // commande d'alimentation du GNSS
#define GPS_EN_ACTIVE     HIGH  // niveau qui ALLUME le GNSS (selon le montage)
#define PIN_CRSF_RX       16    // ← TX du récepteur (sortie série du ER5C-i)
#define PIN_CRSF_TX       15    // → RX du récepteur
#define PIN_XBUS_RX        5    // libre : X-Bus de l'ESC abandonné (port en entrée, §13)
#define PIN_XBUS_TX        6    // libre (idem) ; ni l'une ni l'autre n'est utilisée
#define PIN_IMU_SDA        8
#define PIN_IMU_SCL        9
#define PIN_IMU_INT1       7
#define PIN_BUTTON         0    // bouton BOOT (actif à l'état bas)
#define PIN_LED_RGB       48    // 48 sur DevKitC-1 v1.0, 38 sur v1.1

// ---------------------------------------------------------------- UART
#ifndef TRIMBOX_QEMU
  #define GNSS_SERIAL Serial1     // UART1
  #define CRSF_SERIAL Serial2     // UART2
#else
  // Variante émulateur (tests/qemu) : QEMU n'émule que UART0 et UART1.
  // Le GNSS partage UART0 avec le journal, le CRSF prend UART1.
  #define GNSS_SERIAL Serial
  #define CRSF_SERIAL Serial1
#endif

// ---------------------------------------------------------------- GNSS
#define GNSS_BAUD         115200
#define GNSS_DYN_MODEL    7     // Airborne 2g (§4.8)
#define MAX_NAVIGATION_RATE 25

// ---------------------------------------------------------------- IMU
#define ACCEL_RANGE_G     16    // ±16 g OBLIGATOIRE (§12.8)
// 1 = moyenne des échantillons IMU (416 Hz) sur la période GNSS : filtre
//     anti-repliement, les vibrations du châssis ne « tombent » plus au
//     hasard sur l'échantillon retenu.
// 0 = dernier échantillon lu (comportement le plus proche d'une lecture
//     ponctuelle).
// [À VALIDER] : comparer la détection du temps en l'air (console,
// MIN_AIR_SAMPLES = 3, seuil 0,35 g) sur un même roulage dans les deux modes.
#define IMU_AVERAGE       1
// Maintien à l'arrêt (core/stillhold.h) : position figée et vitesse à 0
// quand la voiture est immobile. 0 pour enregistrer le GNSS brut.
#define STILL_HOLD        1
// Correspondance des axes selon le montage : AXIS_X_SRC = 0/1/2 pour x/y/z
// du capteur, AXIS_X_SIGN = ±1. Par défaut : capteur à plat, x vers l'avant.
#define AXIS_X_SRC 0
#define AXIS_X_SIGN 1
#define AXIS_Y_SRC 1
#define AXIS_Y_SIGN 1
#define AXIS_Z_SRC 2
#define AXIS_Z_SIGN 1

// ---------------------------------------------------------------- CRSF
#define CRSF_LINE_CHANNEL_DEFAULT 8     // voie de pose de ligne (1..16)
#define CRSF_GPS_PERIOD_MS        200   // 5 Hz
#define CRSF_STATUS_PERIOD_MS     1000  // rappel de l'état, 1 Hz
#define CRSF_GPSTIME_PERIOD_MS    1000  // date et heure GPS, 1 Hz (ExpressLRS ≥ 4.1)
// Messages texte (chrono, accusés) : ExpressLRS ne garde que le DERNIER
// message « mode de vol » en attente d'envoi radio. Deux messages envoyés
// coup sur coup = le premier perdu. Chaque message est donc tenu seul
// pendant CRSF_EVENT_HOLD_MS (renvoyé toutes les CRSF_EVENT_SPACING_MS),
// puis le suivant de la file prend sa place.
#define CRSF_EVENT_HOLD_MS        700
#define CRSF_EVENT_SPACING_MS     150
#define CRSF_MIN_GAP_MS           10    // au plus une trame toutes les 10 ms
#define LINE_MIN_SPEED_MMS        2000  // pose immédiate au-dessus de 2 m/s (cap GNSS)
#define LINE_ARM_WINDOW_MS        10000 // en dessous : ligne armée, démarrer dans les 10 s
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

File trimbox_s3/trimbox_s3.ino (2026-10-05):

// ============================================================================
//  TrimBox — enregistreur GPS/inertiel pour voitures RC
//  ESP32-S3 (N16R8), GNSS u-blox M10, IMU LSM6DS3, télémétrie CRSF.
//
//  Spécification : CAHIER-DES-CHARGES.md.
//  Tout le code est dans src/ : ce fichier ne fait que l'appeler.
//  La logique sans matériel (src/core) est testée sur PC : tests/native.
// ============================================================================
#include "src/app.h"

void setup(){ app::setup(); }
void loop(){ app::loop(); }

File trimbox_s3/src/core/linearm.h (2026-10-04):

// ============================================================================
//  Pose de ligne « à l'arrêt, puis on démarre ».
//
//  La voiture est posée SUR la ligne voulue, à l'arrêt. La commande de pose
//  « arme » la ligne : la position est mémorisée (ancrage), mais le cap n'est
//  pas encore connu. Dès que la voiture démarre (dans les `startWindowMs`),
//  on suit son déplacement ; le cap de la ligne est celui du départ :
//    - cap GNSS (effet Doppler, précis) dès que la voiture a parcouru
//      `headDistM` à plus de `headSpeedMms` ;
//    - à défaut, direction ancrage → position actuelle, une fois `bearingDistM`
//      parcourus (plus lent au démarrage, mais toujours juste).
//  La ligne est posée `offsetM` DEVANT l'ancrage : la voiture, partie de
//  derrière, la franchit réellement, ce qui déclenche le chrono (dragster :
//  départ arrêté ; circuit : début du premier tour).
//
//  Sans dépendance matérielle : testé sur PC.
// ============================================================================
#pragma once
#include <stdint.h>

namespace linearm {

struct Settings {
  uint32_t startWindowMs = 10000;  // délai pour DÉMARRER après la commande
  uint32_t placeWindowMs = 10000;  // délai pour obtenir le cap une fois parti
  int32_t  moveMms       = 500;    // « la voiture roule » : > 1,8 km/h…
  float    moveDistM     = 1.5f;   // … ou éloignée de 1,5 m de l'ancrage
  int32_t  headSpeedMms  = 2000;   // cap GNSS fiable au-dessus de 7,2 km/h
  float    headDistM     = 3.0f;
  float    bearingDistM  = 6.0f;
  float    offsetM       = 0.5f;   // ligne posée devant l'ancrage
};

enum class Which : uint8_t { Start = 0, Finish = 1 };

struct Result {
  enum Kind : uint8_t { None, Moving, Placed, Timeout } kind = None;
  Which which = Which::Start;
  int32_t lat = 0, lon = 0;        // ligne posée, deg × 1e7
  int32_t headingE5 = 0;           // cap, deg × 1e5 (0 = nord, sens horaire)
  bool fromDoppler = false;        // cap GNSS (true) ou direction du déplacement
};

class Armer {
public:
  void configure(const Settings& s){ s_ = s; }
  void arm(Which w, int32_t lat, int32_t lon, uint32_t nowMs);
  void cancel(){ active_ = false; }
  bool active() const { return active_; }
  bool moving() const { return moving_; }
  Which which() const { return which_; }
  uint32_t armedAt() const { return armedAt_; }

  // À chaque solution GNSS.
  Result update(uint32_t nowMs, bool fix, int32_t lat, int32_t lon, int32_t gSpeedMms, int32_t headMotE5);

  static double distM(int32_t lat1, int32_t lon1, int32_t lat2, int32_t lon2);
  static double bearingDeg(int32_t lat1, int32_t lon1, int32_t lat2, int32_t lon2);
  static void offset(int32_t& lat, int32_t& lon, double headingDeg, double meters);

private:
  Settings s_;
  bool active_ = false, moving_ = false;
  Which which_ = Which::Start;
  int32_t aLat_ = 0, aLon_ = 0;
  uint32_t armedAt_ = 0, movedAt_ = 0;
};

} // namespace linearm

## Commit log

2026-10-04 cahier des charges unique 3.0, état du projet, guide de reprise
    [partitions.csv]
2026-10-05 voix des annonces dans lua/SOUNDS
2026-10-05 console 1.7.16 : sélection d'une portion dans la comparaison
    Claude-Session: https://claude.ai/code/session_012Z8LmxLPqA1DRecvv9zmWy
2026-10-05 Renommage du projet en TrimBox (firmware 2.0-a14, console 1.7.17)
    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
    [partitions.csv, trimbox-boitier.3mf]
2026-10-05 tests/web : bloquer tout accès hors du module (correction du job Console embarquée sur GitHub)
    Le filtre « **/arcgisonline.com/** » ne reconnaissait pas l'hôte
    server.arcgisonline.com : sur le runner GitHub, qui a Internet, les tuiles
    satellite arrivaient et le message « pas d'Internet » attendu n'apparaissait
    jamais (délai dépassé). Toute requête hors de 127.0.0.1 est désormais refusée,
    et le test vérifie que les tuiles ont bien été interceptées.
    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
2026-10-05 Voix : script de génération à la demande (tools/sons/generer-mot)
    Demande le texte et le nom du fichier, fait écouter le résultat (garder,
    réécouter, changer le texte, plus lent / plus rapide, abandonner) et le range
    dans SOUNDS\trimbox\. Même voix et même format que generer-voix (Azure
    fr-FR-DeniseNeural, WAV 16 bits mono 16 kHz). Clé mémorisable dans
    azure-cle.txt, ignoré par git. Inventaire des fichiers du JSON d'état remis
    à jour.
    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
2026-10-05 Nom du véhicule et mot de passe Wi-Fi modifiables depuis la console (firmware 2.0-a15, console 1.7.18)
    - Message FF F3 : lecture (nom + mot de passe personnalisé ou non, jamais
    le mot de passe) et écriture (masque, nom 16, mot de passe 63).
    - core/ident : règles de saisie, noms dérivés (TrimBox-<nom> en Wi-Fi,
    TrimBox <nom> en Bluetooth), codage ; tests natifs.
    - hw/identity : mémorisation en NVS (la partition cfg est pleine, la table
    de partitions ne change pas) ; ACK puis redémarrage sous le nouveau nom.
    Refusé pendant un enregistrement, un roulage, un téléchargement, un
    effacement ou la validation d'une mise à jour.
    - Port série : touche x pour revenir au nom et au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
    [app.cpp, config.h]
2026-10-07 CI : publication automatique d'une release GitHub quand tout est vert
    - Nouveau job « Publication (release GitHub) » : sur main, après succès des
    tests, de la compilation, de la console et de l'émulateur, crée la release
    firmware-<FIRMWARE_VER> (Latest) si cette version n'est pas déjà publiée.
    - Fichiers joints : trimbox_s3-app.bin (Wi-Fi), trimbox_s3-complet.bin (0x0),
    bootloader et partitions séparés, index.html, trimbox-radio.zip (script Lua,
    LISEZMOI, SOUNDS), SHA256SUMS.txt.
    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
2026-10-07 CI : délais maximaux et nouvelles tentatives sur les téléchargements
    Le job émulateur est resté bloqué plus de 20 min à l'étape « Outils »
    (téléchargement sans réponse), ce qui retardait la publication de la release.
    - timeout-minutes sur chaque job (tests 15, compilation 30, console 25,
    émulateur 45, publication 10) au lieu des 6 h par défaut ;
    - curl : --retry 4 --retry-all-errors, connexion 30 s, 15 min au plus ;
    - apt-get : 3 tentatives, 60 s par requête.
    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
2026-10-07 Vitesse nulle et plus de faux départ voiture posée (firmware 2.0-a16)
    Essai réel du 07/10/2026 : voiture posée, 4 à 5 satellites, le GPS annonçait
    0 à 5,8 km/h ; le maintien à l'arrêt (seuils GNSS fixes 1,1 / 2,2 km/h) ne
    s'enclenchait presque jamais, la vitesse affichée était incohérente et une
    pointe au-dessus de 5 km/h démarrait l'enregistrement automatique.
    - hw/imu : agitation par époque (écart-type des échantillons, 3 axes
    combinés, insensible aux biais), imu::activity().
    - core/stillhold : l'IMU tranche seule quand l'agitation est mesurable :
    figée après 0,4 s de calme (≤ 25 mg, ≤ 3 °/s) quelle que soit la vitesse
    GNSS ; libérée après 2 époques agit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
    [app.cpp, config.h, imu.cpp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]
2026-10-15 Nouvelle carte NiceMCU ESP32-S3 Mini Nano N16R8 (firmware 2.0-a17)
    Même puce (ESP32-S3R8, PSRAM octale 8 Mo) et même flash 16 Mo que la
    DevKitC-1 N16R8 : compilation, partitions et brochage inchangés, toutes les
    broches utilisées sont sorties sur la carte.
    - config.h : HARDWARE_VER « ESP32-S3 Mini Nano N16R8 » (Bluetooth 2A27) ;
    GPIO 33-37 interdits (sortis sur la carte mais réservés à la PSRAM) ;
    DEL RGB sur 48 à confirmer.
    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
2026-10-17 PCB support : ESP32-S3 Mini Nano + LSM6DS3TR-C + régulateur 5 V + JST GPS/récepteur
    - hardware/pcb-support : PCB 2 couches 23,4 × 29 mm à la taille de la carte
    ESP32 (rien sous l'antenne), IMU soudée par JLCPCB, TPS563201 alimenté par
    le BEC, diode anti-retour USB, J1 JST SH 5 (récepteur + BEC), J2 JST SH 4
    (GPS, ordre G V T R).
    - Générateur Python (src/) : modèle unique → routage A* 2 couches, DRC et
    continuité au 0,01 mm, projet KiCad 5.1 (import EasyEDA), Gerber + perçages,
    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
2026-10-17 PCB support : visualiseur 2D/3D et étiquette RX/BEC déplacée
    - apercus/visualiseur.html : vues 3D (montage complet, éclaté, dessus /
    dessous / profil) et 2D (deux faces + ESP32 montée), survol des composants
    avec référence, valeur et code LCSC ; textures tirées des mêmes données
    que les Gerber (src/viewer_data.py, viewer_template.html, viewer_build.py).
    - Sérigraphie : « RX/BEC » ne chevauche plus le contour de J1.
    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
2026-10-17 PCB support : J1 remplacé par deux picots servo coudés (J1 TX, J3 RX)
    - Deux picots coudés 2,54 mm 1×3 (S, +, −) au bord gauche : deux rallonges
    servo ordinaires depuis les sorties 2 (TX → IO16) et 3 (RX ← IO15) du
    récepteur ; le + amène le BEC. À souder soi-même (hors BOM JLCPCB).
    - GPS (J2, JST SH 4) remonté en haut à gauche ; trous de tenue des rangées 1-2
    gauche retirés ; C8 près de J2 ; routage refait.
    - Contrôle : aucune erreur (isolement 0,17 mm), réseaux continus, KiCad et
    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
2026-10-17 PCB support : pastilles à souder pour les fils du récepteur (plus rien ne dépasse)
    - J1 : 4 pastilles traversantes (trou 1,1 mm, pas 3 mm) TX, RX, +, − au
    bord gauche, à la place des picots coudés (J3 supprimé) : fils de deux
    rallonges servo coupées, aucune excroissance hors du contour.
    - Routage refait ; contrôle : aucune erreur (isolement 0,177 mm), réseaux
    continus, KiCad et Gerber revérifiés.
    - Schéma, sérigraphie, notice et visualiseur 2D/3D à jour.
    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
2026-10-17 PCB support : 2 picots de tenue en haut à gauche, connexions décalées vers le bas
    - Trous de tenue rangée 1 gauche (IO3, IO1) rétablis : l'ESP32 est tenue
    aux deux bouts du côté gauche (rangées 1 et 11) et sur toute la droite.
    - Connecteur GPS J2 et pastilles J1 descendus ; C8 suit J2 ; routage refait.
    - Contrôle : aucune erreur, réseaux continus, KiCad et Gerber revérifiés.
    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
